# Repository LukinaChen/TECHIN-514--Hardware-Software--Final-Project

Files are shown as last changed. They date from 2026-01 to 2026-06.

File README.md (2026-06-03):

# SnoreSense – A Snoring-Based Sleep Quality Indicator

## Project Overview
SnoreSense is a connected sleep quality indicator designed to help users become aware of their sleep patterns through snoring detection. A sensing device placed near the bed detects and counts snoring events overnight using audio sensing and simple signal processing. The processed data is converted into a sleep quality score and transmitted wirelessly to a paired display device, which visualizes the score using a physical gauge interface.
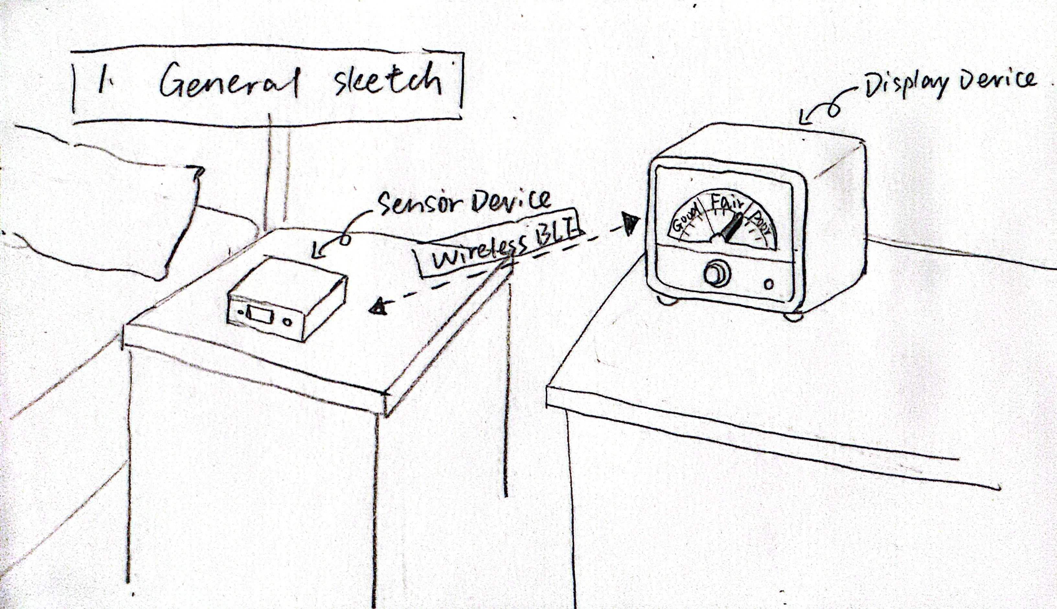
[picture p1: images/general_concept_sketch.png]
General Concept Sketch


## Demo Video
Demo Video (https://www.youtube.com/watch?v=h0CMzlRr8LE)

## Sensor Device – Snoring Detection Unit
The sensing device is placed near the user’s bed and is responsible for detecting snoring activity during sleep. It uses a digital MEMS microphone (INMP441) to capture audio signals and an ESP32 microcontroller to process the data locally. Simple digital signal processing techniques are applied to detect and count snoring events overnight. The summarized results are then transmitted wirelessly to the display device.

**Key hardware components:**

Microcontroller: Seeed Studio XIAO ESP32-C3

Microphone: INMP441 (Part No. 441NP0552) Digital MEMS Microphone

Power: 3.7V 1000mAh LiPo battery

Charging Module: TP4056 Lithium Battery Charger Module

Power Management: SPST Slide Switch for physical battery isolation

Logic: Timed Wake-up strategy (1Hz duty cycle) – The system samples audio for 200ms every second and remains in Deep Sleep for the remaining 800ms.

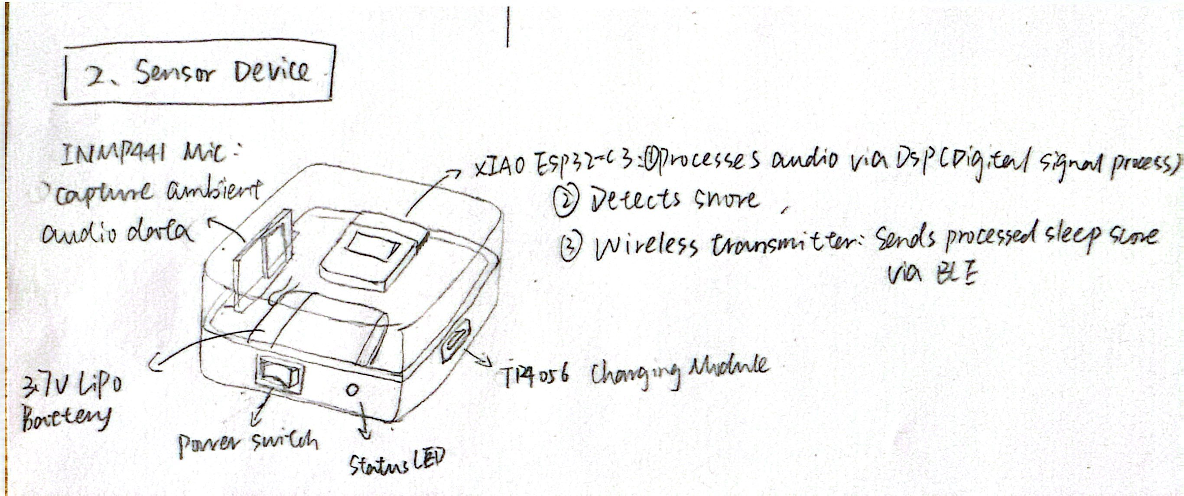
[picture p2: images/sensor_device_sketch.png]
Sensor Device Sketch


The device is designed for fully automated operation. The LED serves as a transient event indicator (5% duty cycle), blinking only when a potential snore is detected or during brief wireless data syncs via ESP-NOW.

**The Scoring Metric** 

1. Total Snore Count: Every 1-second interval that hits the threshold.

2. Bout Count: How many times the user started snoring after at least 2 minutes of silence.

*Logic Criteria (Example for 8hrs)* 
- Good: Minimalsnoring,< 50 total snores AND < 3 Bouts
- Fair: Occasional,snoring,50–200 total snores OR 3–10 Bouts
- Poor: Frequent/Heavy snoring,> 200 total snores OR > 10 Bouts

## Display Device – Sleep Quality Gauge
The display device provides a physical and glanceable visualization of sleep quality data received from the sensing device. It uses a stepper-motor-driven gauge needle to represent sleep quality levels, allowing users to quickly understand their sleep performance.It provides a physical and glanceable visualization of sleep quality data. It features a custom-designed PCB that integrates a high-precision automotive-grade stepper motor and user interaction components.An LED provides a simple on/off indication of snoring activity. The device receives data wirelessly and updates the display accordingly.  

**Key hardware components:**

Microcontroller: Seeed Studio XIAO ESP32-C3 (U1) 

Stepper Motor: Juken X27.168 Stepper Motor (Direct Drive via GPIO)

Indication: Standard 5mm LED (D1) + 220Ω Resistor (R1)

User Input: 6x6mm Tactile push button (SW1) with 10kΩ pull-up resistor (R2) 

Power Solution: 3.7V LiPo battery via JST-PH 2-pin connector (J2)

Power Management: SPST Slide Switch (Master Power) to ensure zero parasitic drain when not in use. 

Circuit Stability: 0.1µF (C1) and 10µF (C2) ceramic capacitors for decoupling and voltage stability. 

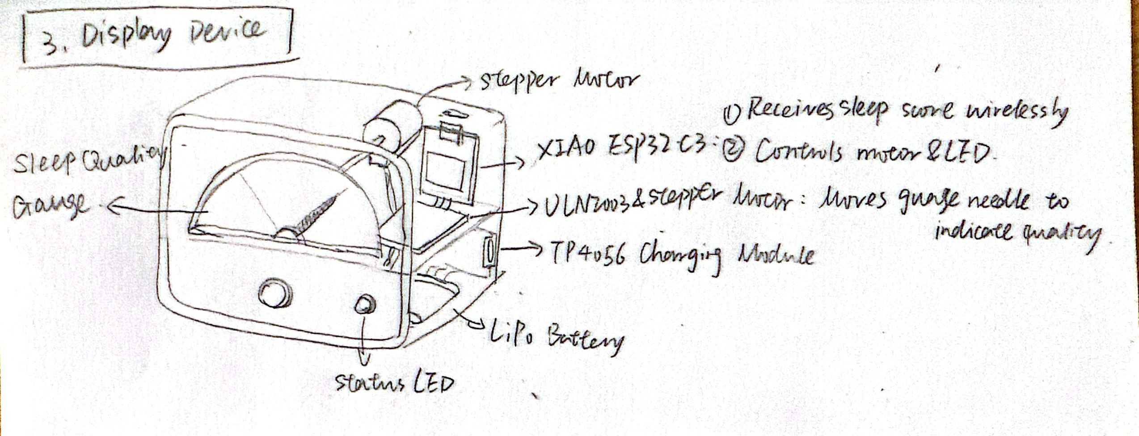
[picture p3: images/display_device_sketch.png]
Display Device Sketch


The X27 stepper motor is only energized when the sleep quality score changes. The Push Button (SW1) allows the user to manually trigger a gauge calibration (homing) or wake the device from deep sleep.

## System Architecture & Communication Diagram
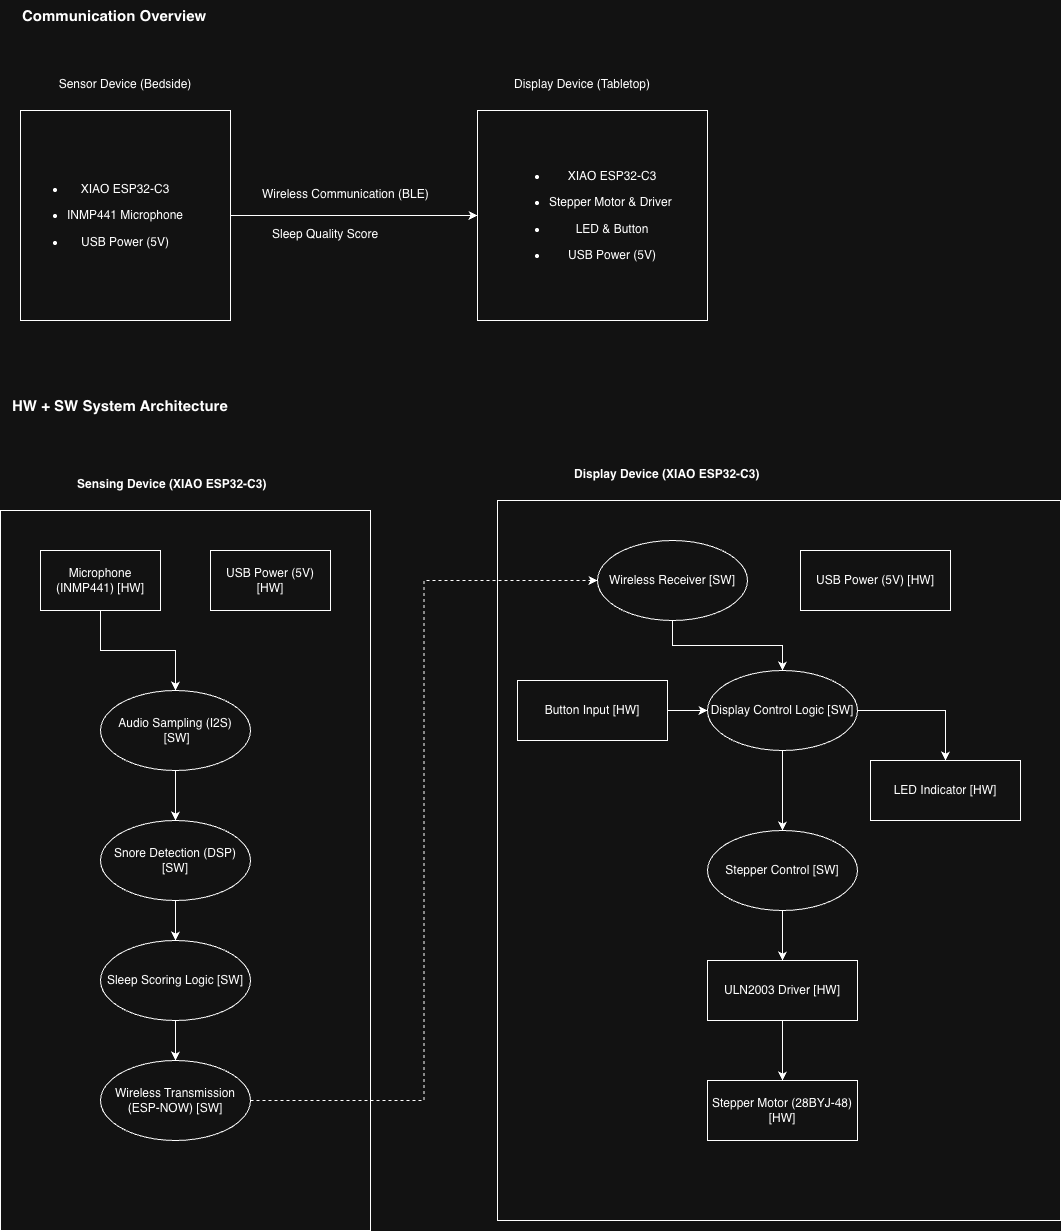
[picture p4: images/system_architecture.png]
System Architecture Diagram


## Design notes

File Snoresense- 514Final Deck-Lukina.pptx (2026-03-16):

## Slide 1

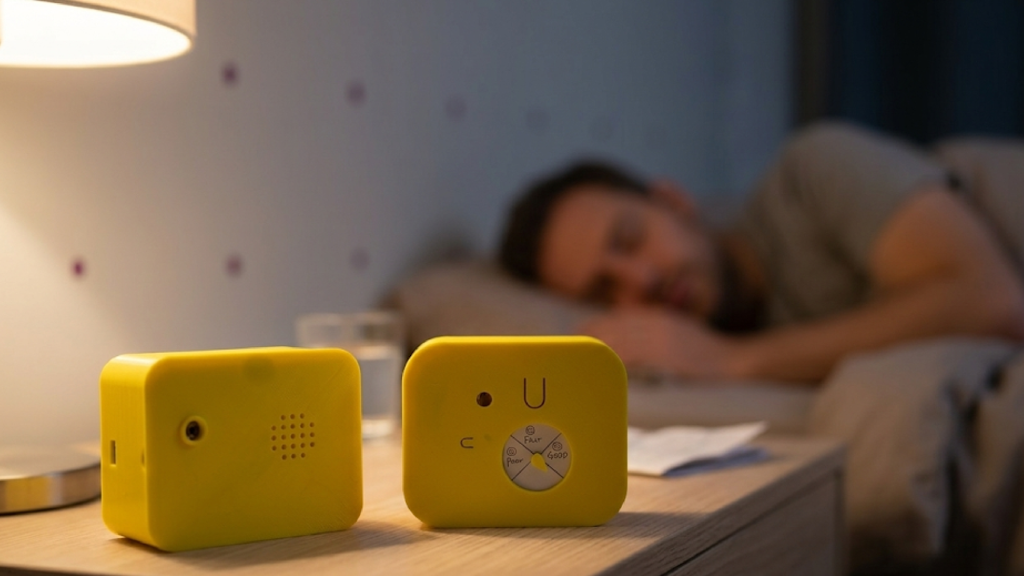
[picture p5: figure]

SnoreSense

A Snoring-Based Sleep Quality Indicator

IOT SLEEP MONITORING SYSTEM

GitHub repo: https://github.com/LukinaChen/TECHIN-514--Hardware-Software--Final-Project

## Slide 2

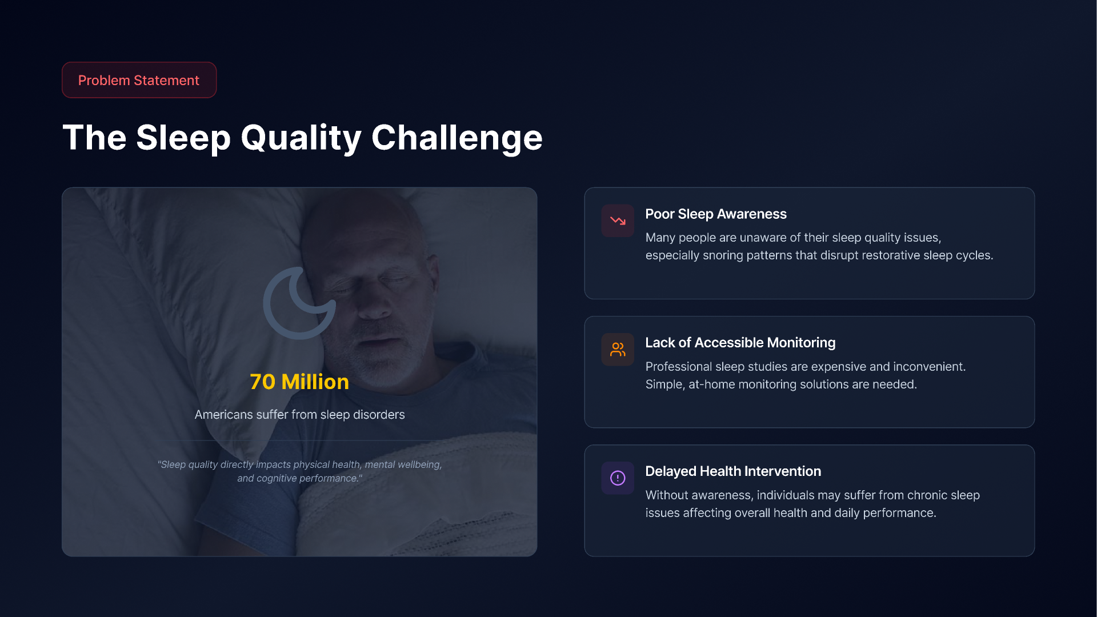
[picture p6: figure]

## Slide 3

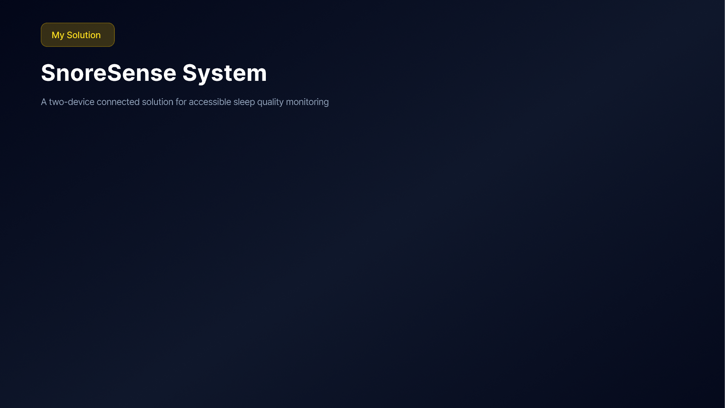
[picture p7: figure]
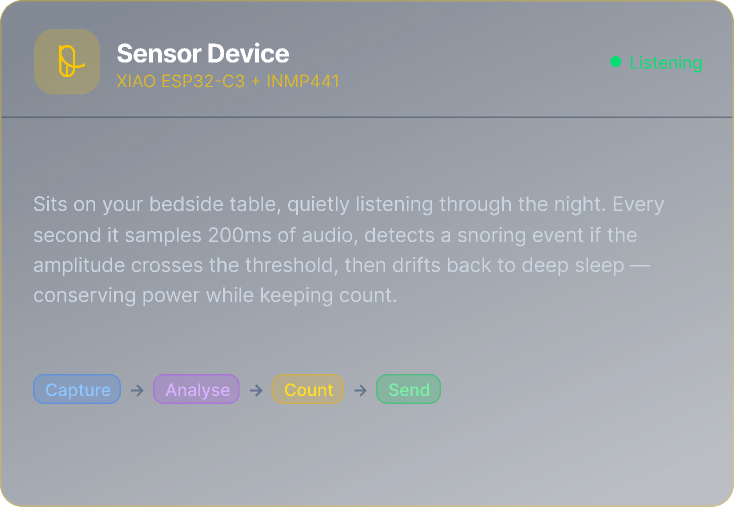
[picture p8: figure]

ESP-NOW

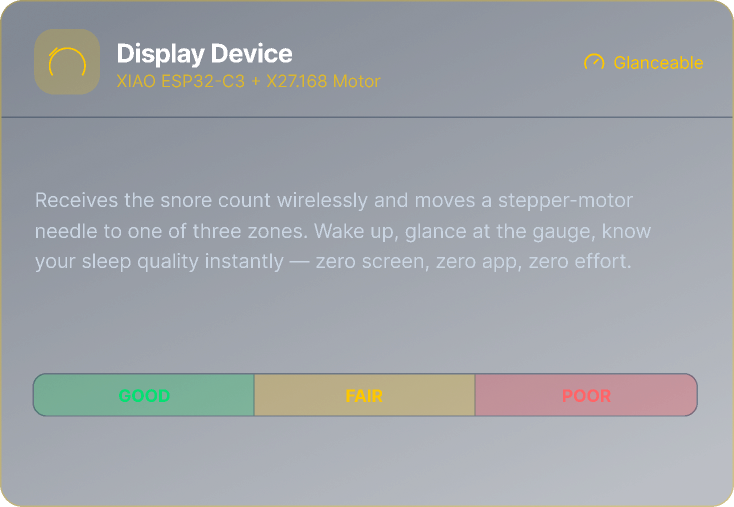
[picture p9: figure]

Wireless ESP-NOW

Direct peer-to-peer, no router needed

Ultra-Low Power

Multi-night runtime on a single charge

No App Required

Physical gauge — readable in seconds

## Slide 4

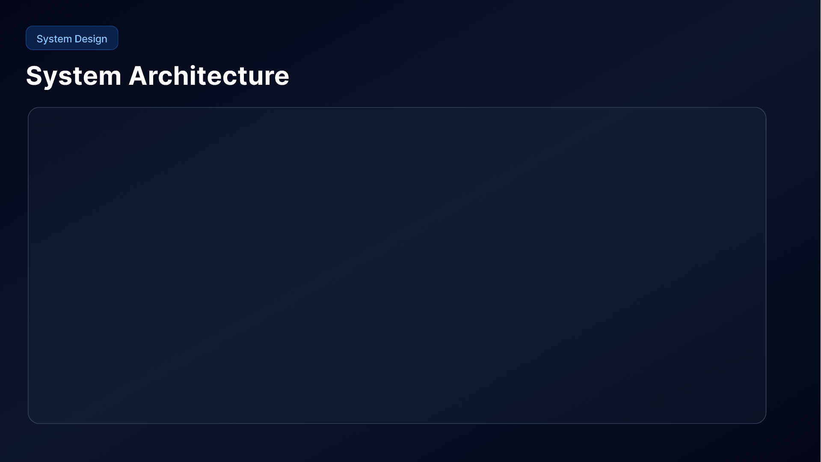
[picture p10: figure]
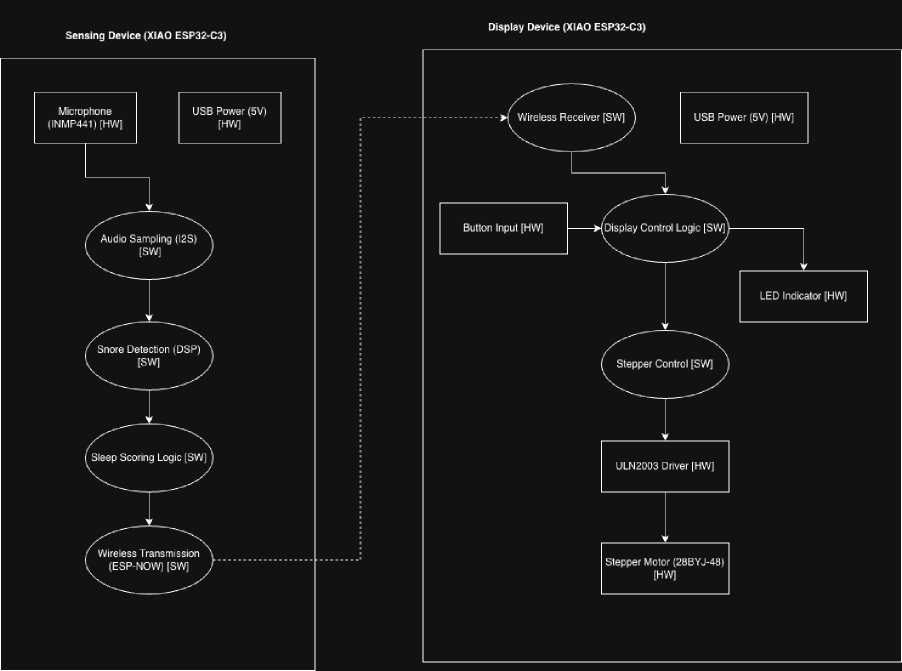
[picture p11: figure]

4 / 12

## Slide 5

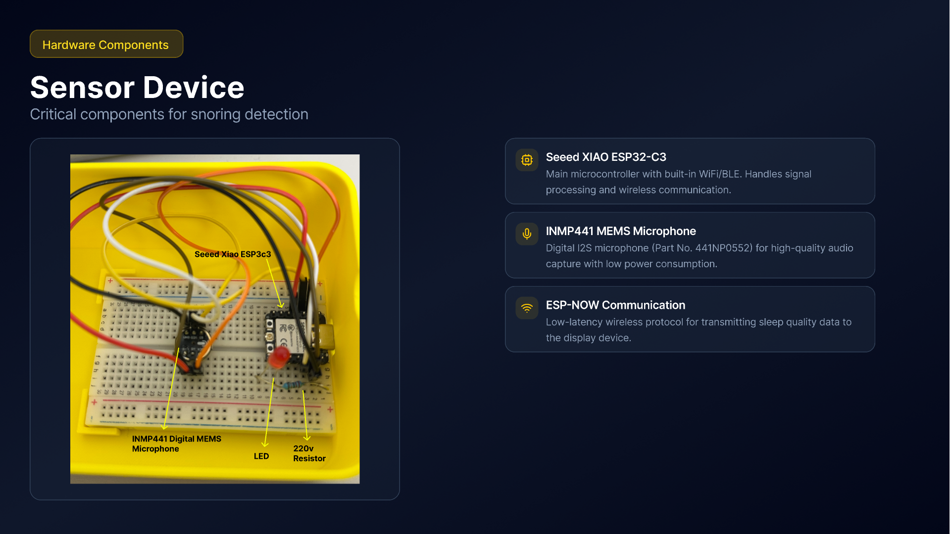
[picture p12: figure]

5 / 12

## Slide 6

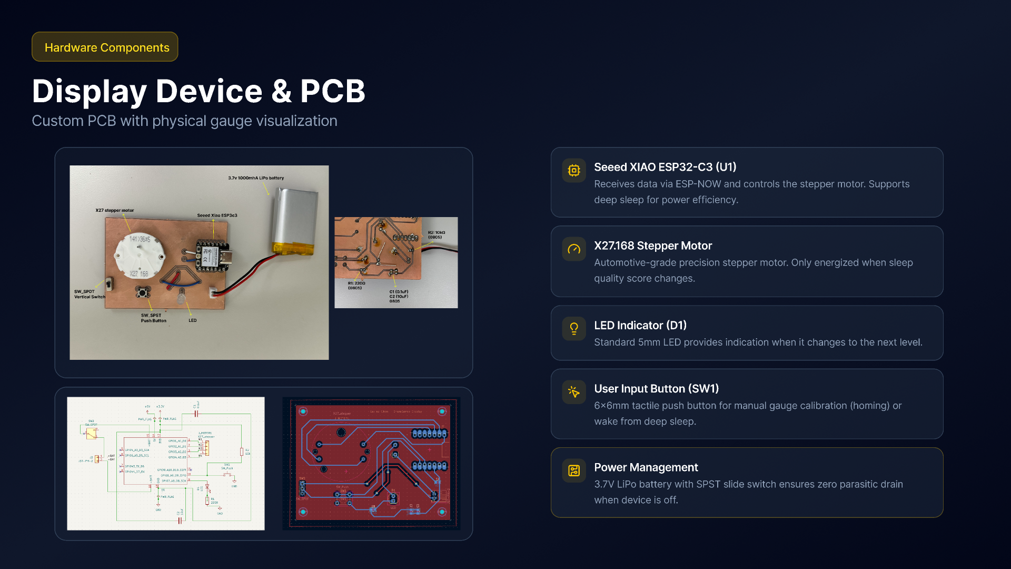
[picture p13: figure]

6 / 12

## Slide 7

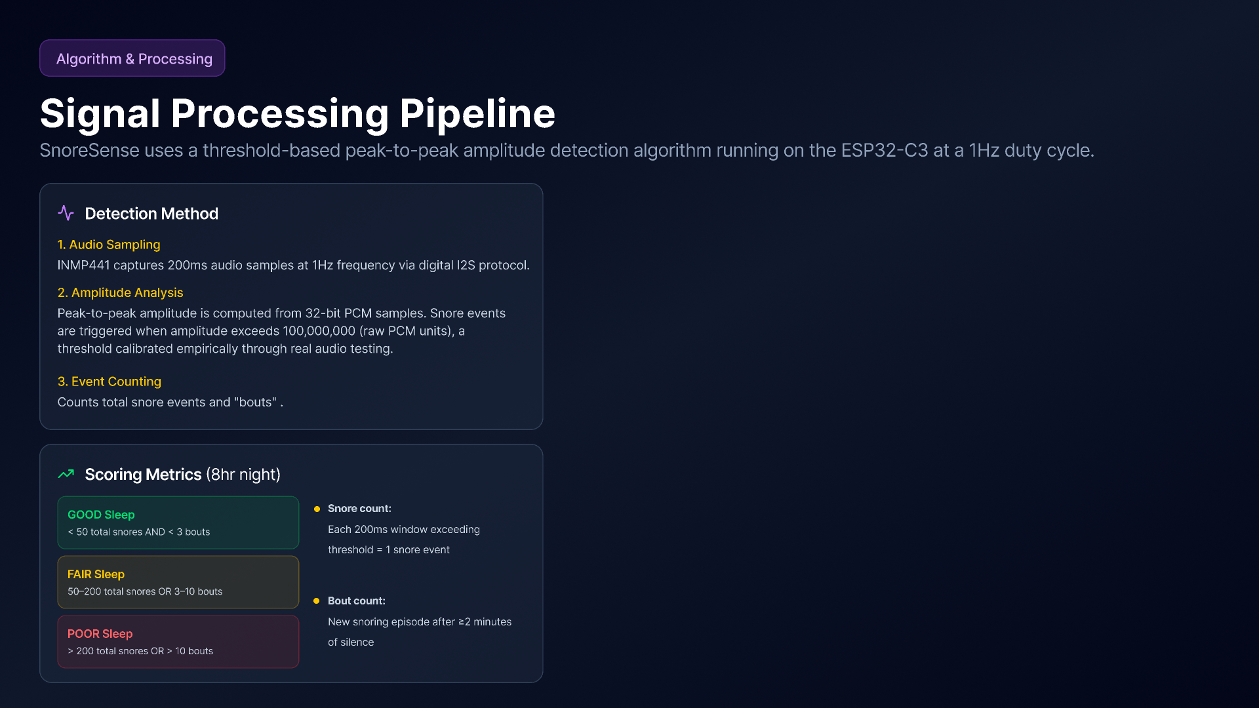
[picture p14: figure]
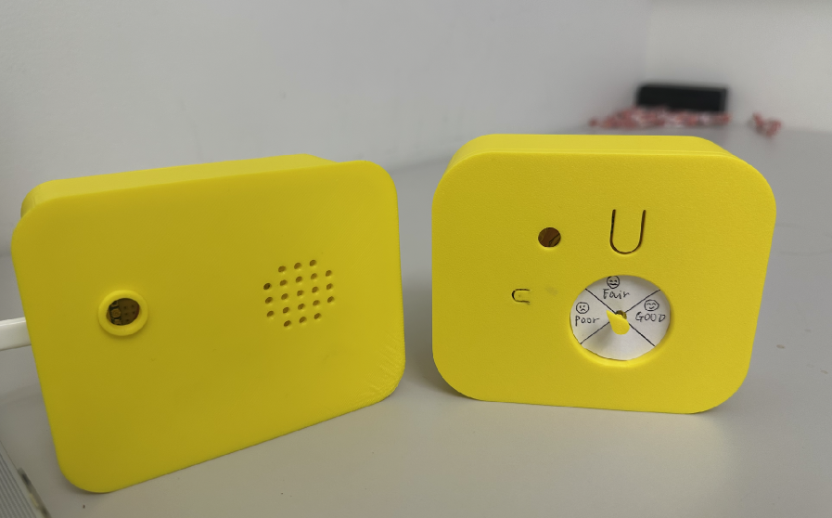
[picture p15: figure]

7 / 12

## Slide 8

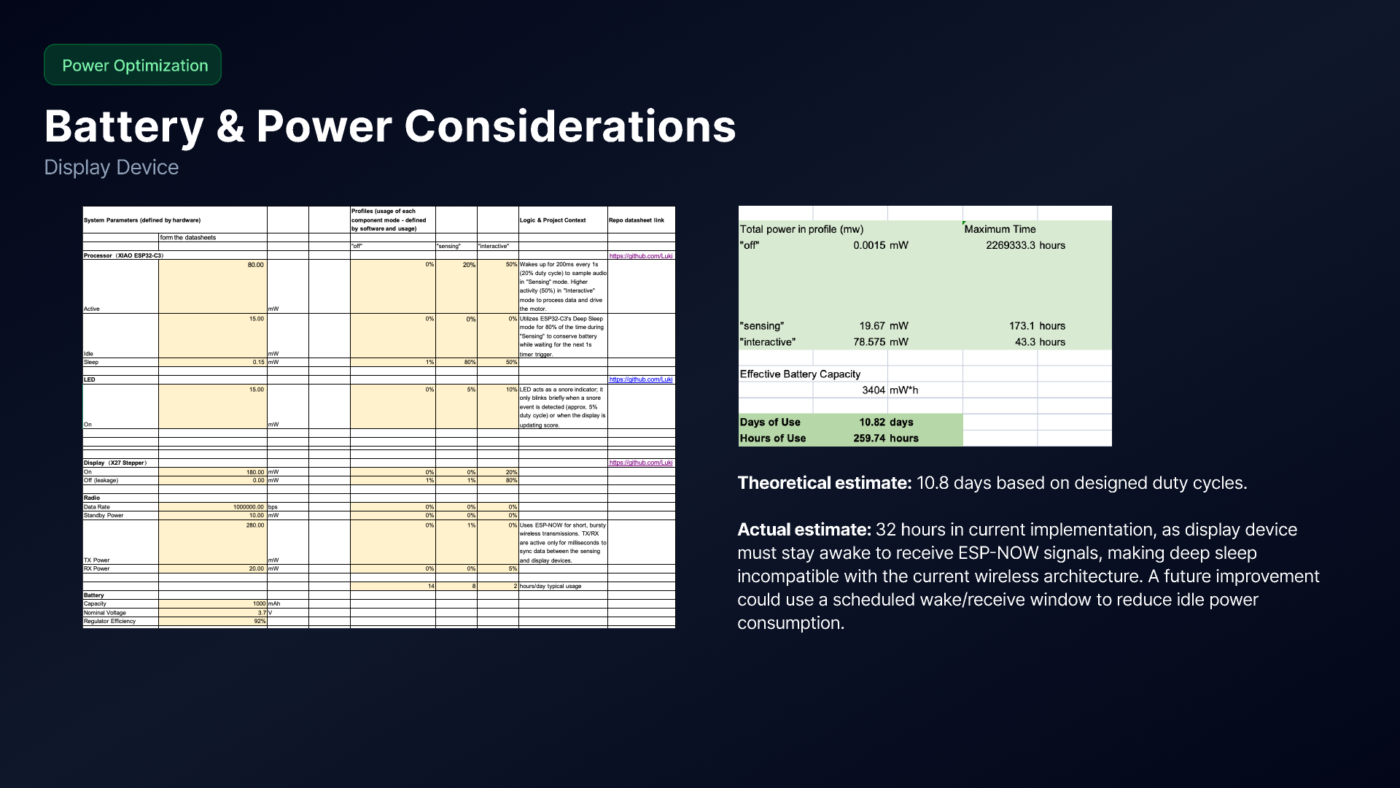
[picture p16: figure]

8 / 12

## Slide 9

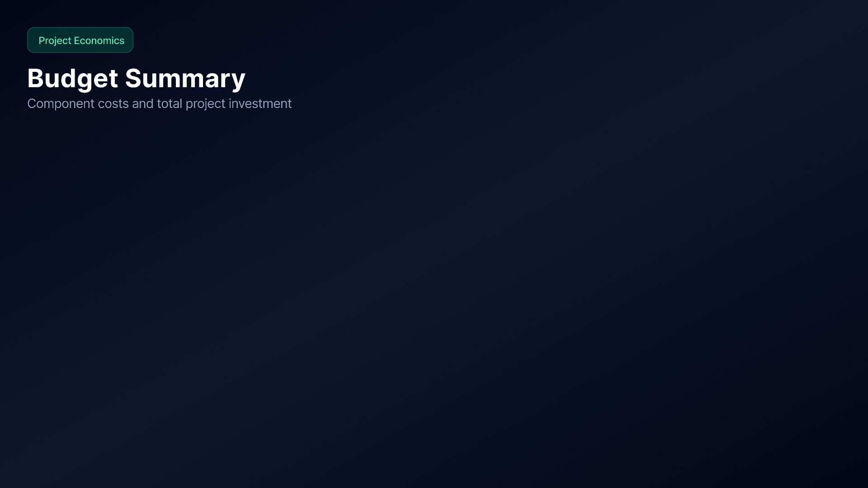
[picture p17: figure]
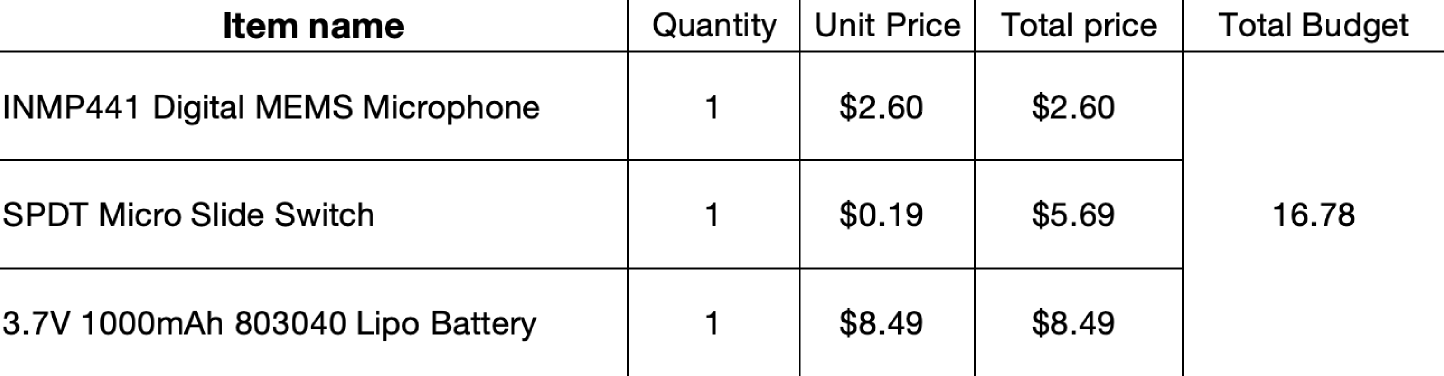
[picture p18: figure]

9 / 12

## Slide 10

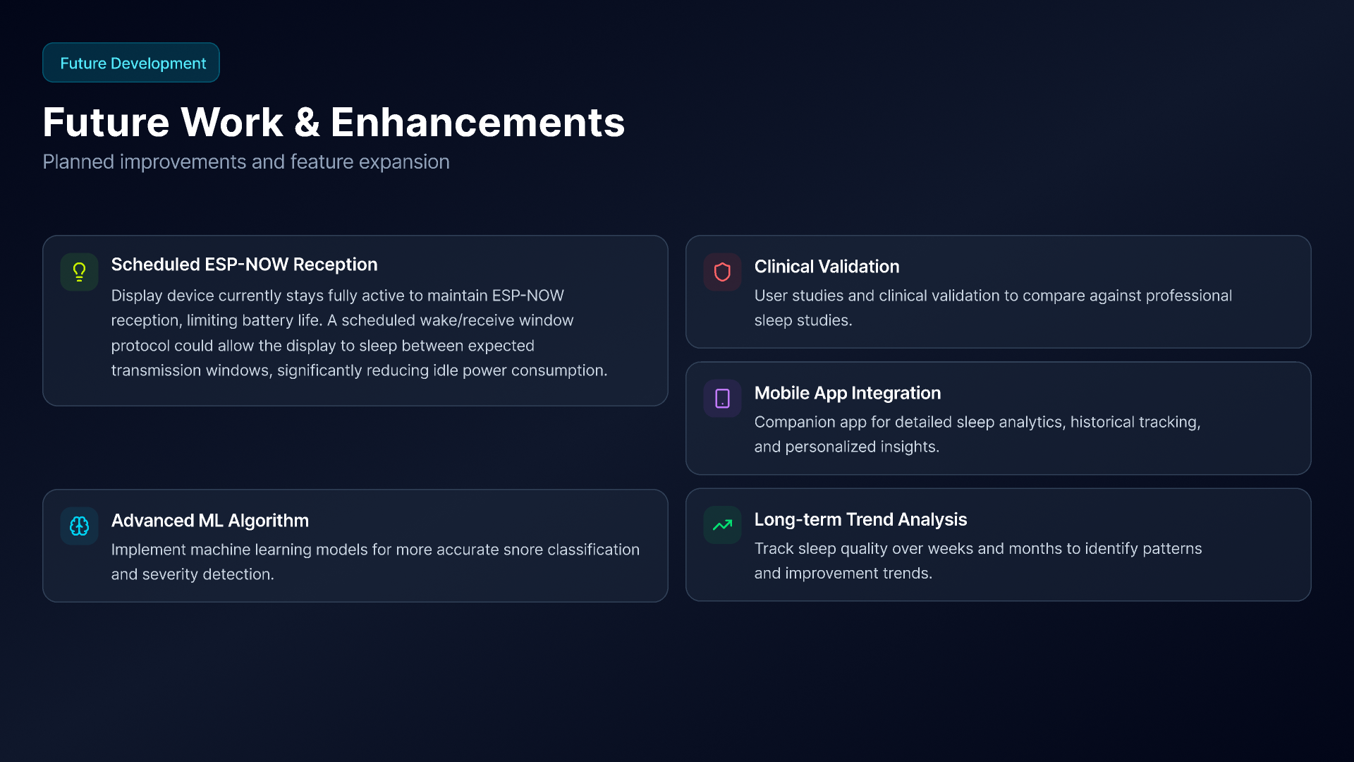
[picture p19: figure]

11 / 12

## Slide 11

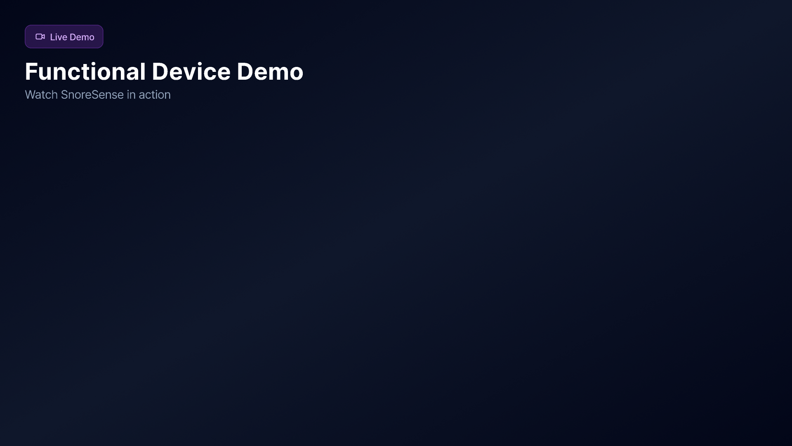
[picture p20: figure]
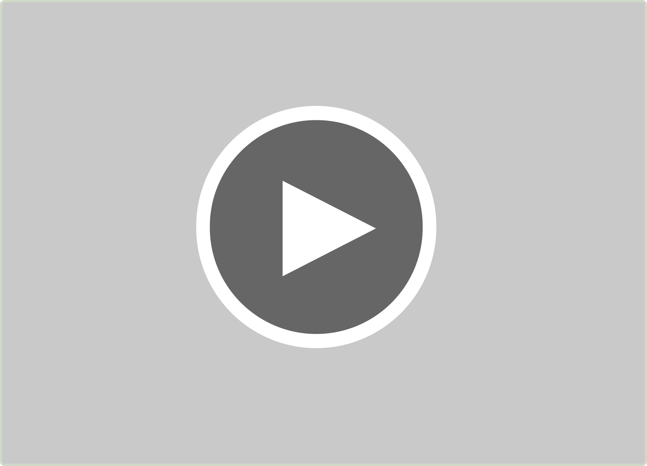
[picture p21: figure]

12 / 12

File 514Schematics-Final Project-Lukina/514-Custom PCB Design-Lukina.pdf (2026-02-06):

### 514-Custom PCB Design

1) All the electronic components that will be soldered to display PCB

Main Control & Interface:

- Microcontroller: Seeed Studio XIAO ESP32-C3 (U1) – Soldered via header pins
- Stepper Motor: X27.168 Stepper Motor (4-pin) – Soldered via through-holes
- Battery Connector: JST-PH 2-pin Connector (2.0mm pitch, right-angle) (J2)
- User Button: 6×6mm Tactile Switch (SW1)

Resistors & LED:

- Resistor (R1): 220Ω – LED current limiting
- Resistor (R2): 10kΩ – Button pull-up resistor
- LED: 5mm LED (Through-hole) (D1)

Capacitors:

- Capacitor (C1): 0.1µF Ceramic – Decoupling
- Capacitor (C2): 10µF Ceramic – Bulk capacitance for 3.3V rail
2) A screenshot of circuit in the Schematic Editor window of KiCad

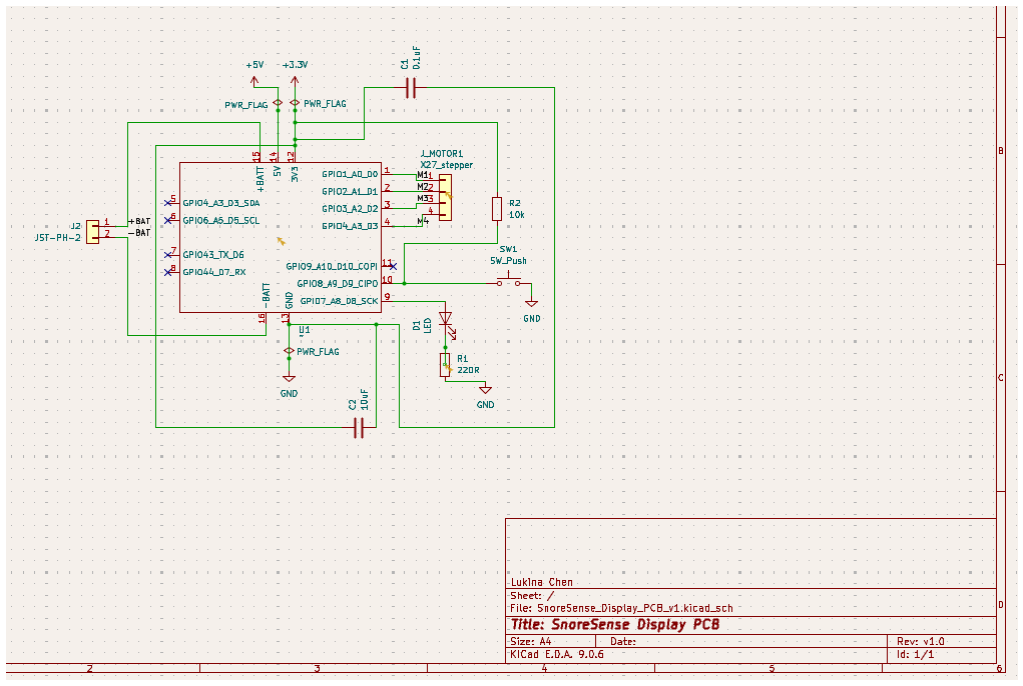
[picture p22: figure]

3) A screenshot of circuit board in the PCB Editor window of KiCad

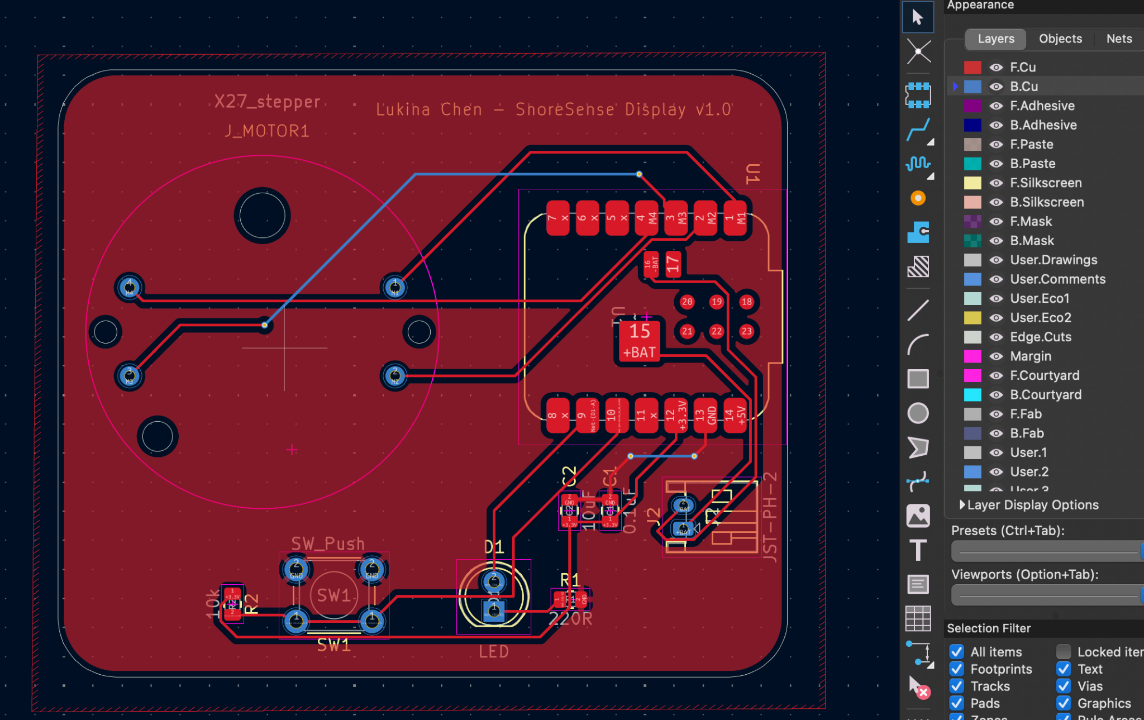
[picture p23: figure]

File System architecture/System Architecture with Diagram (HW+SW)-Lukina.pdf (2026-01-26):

README.md | 2026-01-19

# SnoreSense – A Snoring-Based Sleep Quality Indicator

## Project Overview

SnoreSense is a connected sleep quality indicator designed to help users become aware of their sleep patterns through snoring detection. A sensing device placed near the bed detects and counts snoring events overnight using audio sensing and simple signal processing. The processed data is converted into a sleep quality score and transmitted wirelessly to a paired display device, which visualizes the score using a physical gauge interface.


## Sensor Device – Snoring Detection Unit

The sensing device is placed near the userʼs bed and is responsible for detecting snoring activity during sleep. It uses a digital MEMS microphone (INMP441) to capture audio signals and an ESP32 microcontroller to process the data locally. Simple digital signal processing techniques are applied to detect and count snoring events overnight. The summarized results are then transmitted wirelessly to the display device.

Key hardware components:

Microcontroller: Seeed Studio XIAO ESP32-C3
Microphone: INMP441 Digital MEMS Microphone Power: 3.7V LiPo battery

Charging Module：TP4056 Lithium Battery Charger Module


The sensing device is designed for overnight operation and employs local processing and low-power wireless communication to reduce energy consumption.

## Display Device – Sleep Quality Gauge

The display device provides a physical and glanceable visualization of sleep quality data received from the sensing device. It uses a stepper-motor-driven gauge needle to represent sleep quality levels, allowing users to quickly understand their sleep performance. An LED provides a simple on/off indication of snoring activity. The device receives data wirelessly and updates the display accordingly.

Key hardware components:

Microcontroller: Seeed Studio XIAO ESP32-C3
Stepper Motor: 28BYJ-48 Stepper Motor with ULN2003 Driver Motor Driver: ULN2003 Driver Board
Indication: Standard 5mm LED + 220Ω Resistor
Input: 6x6x5mm Tactile push button
Power: 3.7V LiPo battery


The stepper motor is only activated when the displayed value changes, minimizing power consumption.

## System Architecture & Communication Diagram

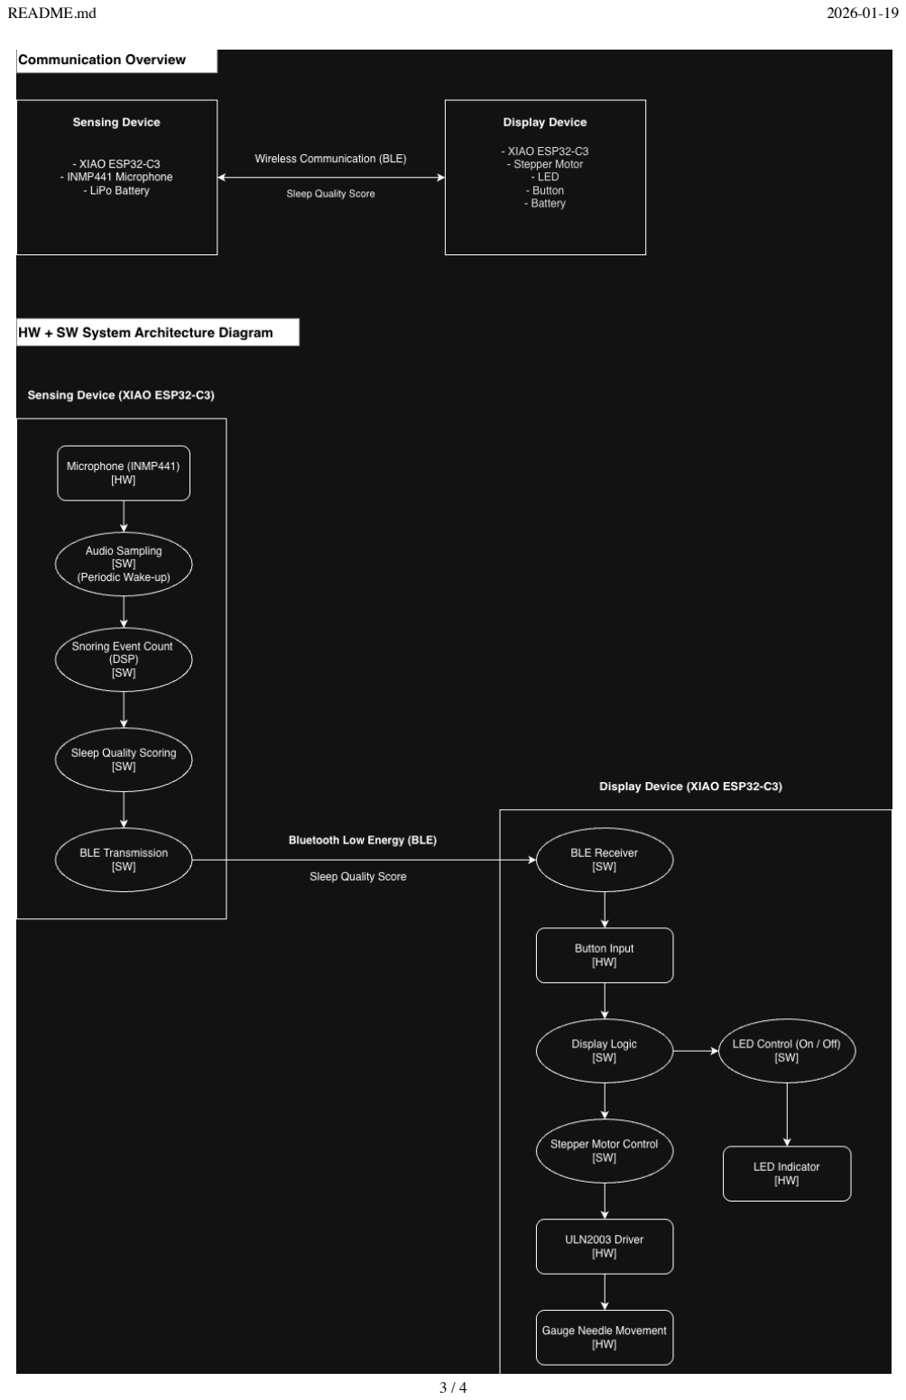
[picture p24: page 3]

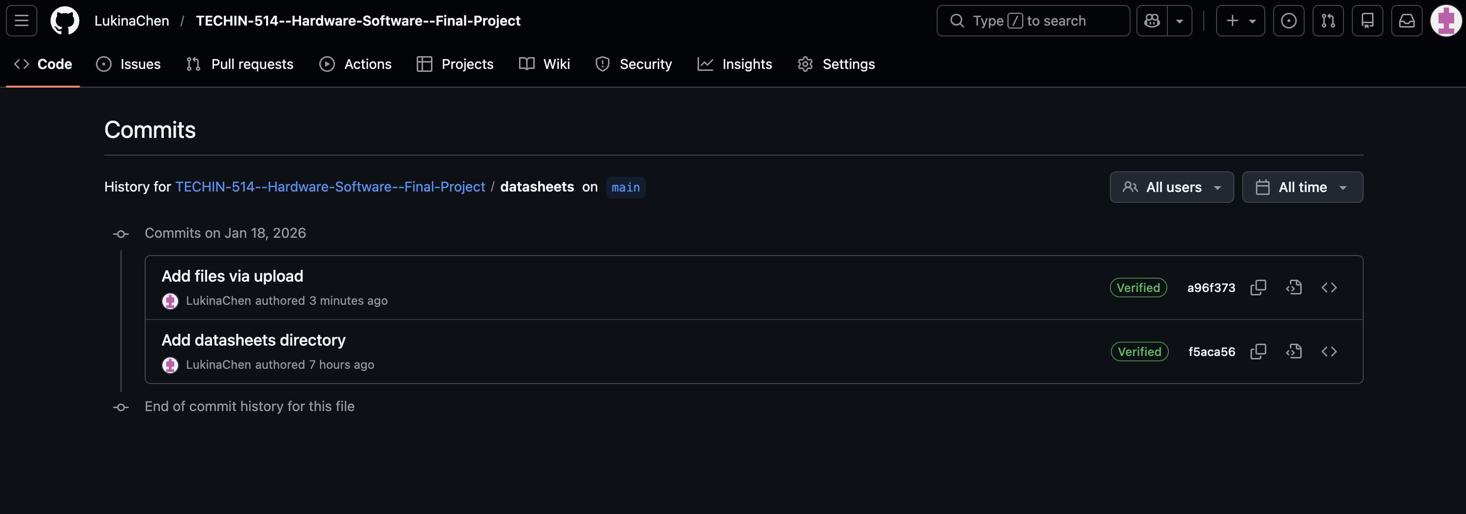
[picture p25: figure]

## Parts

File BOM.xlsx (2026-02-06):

Item ID | Component Name | Description | Part Number | Quantity | Supplier / Notes
1 | Microcontroller | MCU with WiFi/BLE, RISC-V core | Seeed Studio XIAO ESP32-C3 | 2 | 1 for Sensor Device, 1 for Display Device
2 | Microphone | Omnidirectional I2S Digital MEMS Microphone | INMP441 | 1 | For Sensor Device (High precision, Low noise)
3 | Stepper Motor | x27 stepper motor | 28BYJ-48 (5V Version) (TBD) | 1 | For Display Device Gauge
4 | Motor Driver | Darlington Transistor Array Driver Board | ULN2003 Module (TBD) | 1 | Usually sold as a kit with 28BYJ-48
5 | LED | 5mm Red LED (Through-hole) | Generic | 1 | For Snore Activity Indicator
6 | Resistor | 220Ω or 330Ω, 1/4W, 5% | Generic | 1 | Current limiting for LED (Essential)
7 | Push Button | 6x6x5mm Tactile Switch | Generic (B3F series compatible) | 1 | For Reset / User Interaction
8 | USB Cable | USB Type-C Cable | Generic | 2 | Power supply & Data upload for both units
9 | Prototyping Board | PCB | Generic | 2 | For circuit assembly
10 | Jumper Wires | M-M, M-F, F-F DuPont Wires | Generic | 1 Pack | For connections

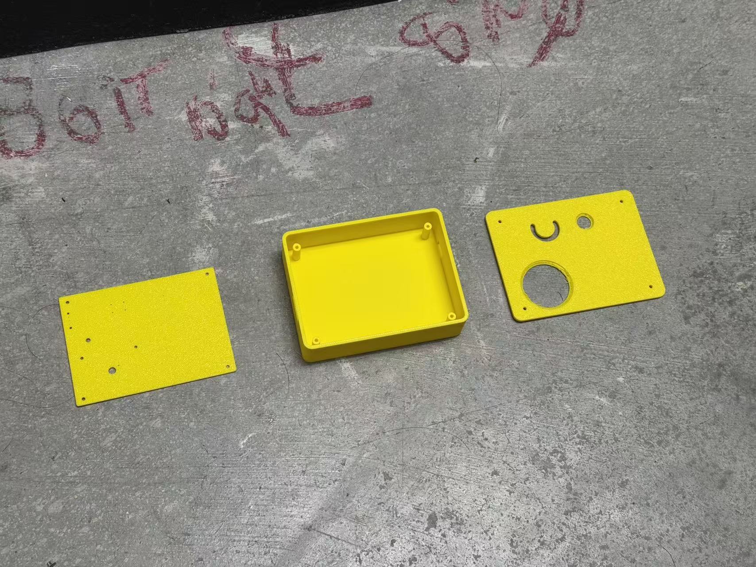
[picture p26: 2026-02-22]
Display Enclosure/parts laid out separately.JPG

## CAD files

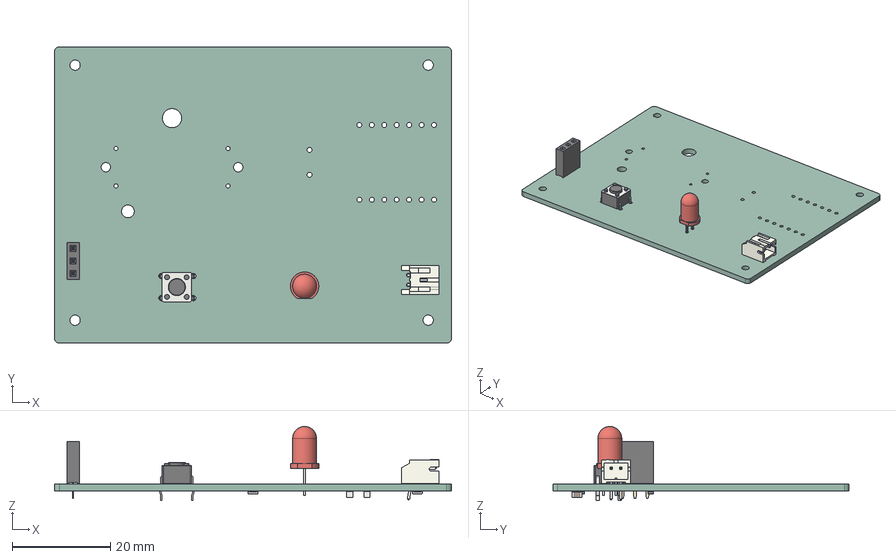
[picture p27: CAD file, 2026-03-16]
Display Enclosure/SnoreSense_Display_PCB_v6.step
81.0 x 60.5 x 15.1 mm
JST_PH_S2B-PH-K_1x02_P2.00mm_Horizontal
LED_D5.0mm
PinSocket_1x03_P2.54mm_Vertical
SW_PUSH_6mm
C_0805_2012Metric x 2
R_0805_2012Metric x 2
SnoreSense_Display_PCB_v1_PCB

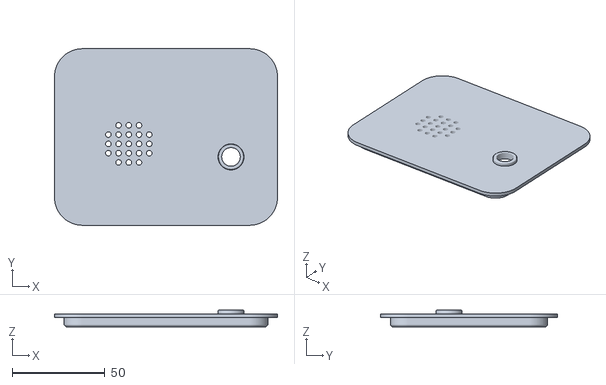
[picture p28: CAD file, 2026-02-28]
Sensor Enclosure/Top case- Lukina.stl
120.0 x 95.0 x 9.00

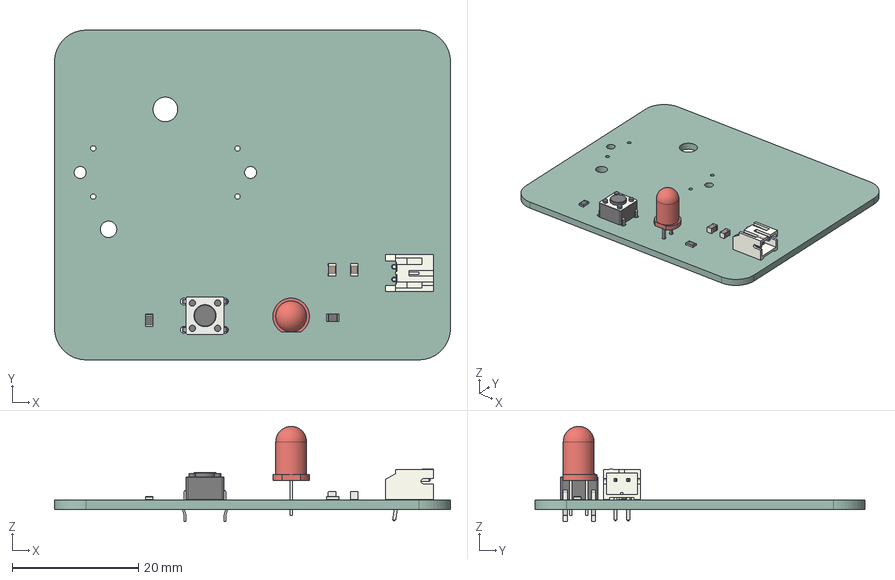
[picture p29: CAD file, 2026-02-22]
SnoreSense_Display_PCB_v1/SnoreSense_Display_PCB_v1.step
62.8 x 52.2 x 15.1 mm
C_0805_2012Metric x 2
R_0805_2012Metric x 2
JST_PH_S2B-PH-K_1x02_P2.00mm_Horizontal
LED_D5.0mm
SW_PUSH_6mm
SnoreSense_Display_PCB_v1_PCB

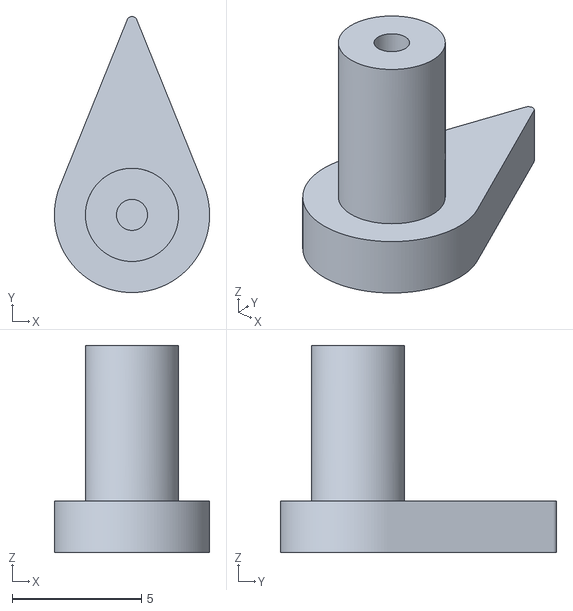
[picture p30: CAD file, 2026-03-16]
Display Enclosure/Needle1-Lukina.stl
6.00 x 10.7 x 8.00

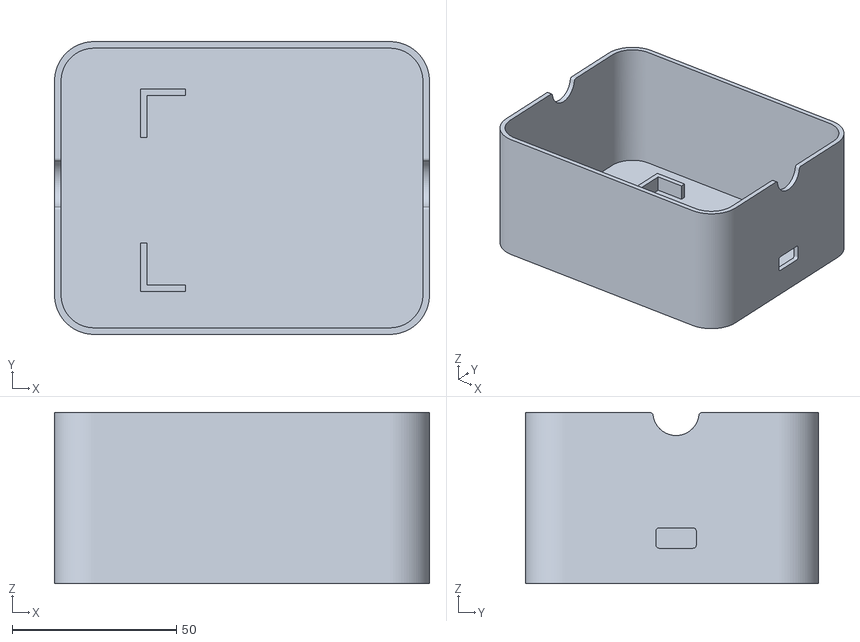
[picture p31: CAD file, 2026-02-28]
Sensor Enclosure/Buttom case- Lukina.stl
114.0 x 89.0 x 52.0

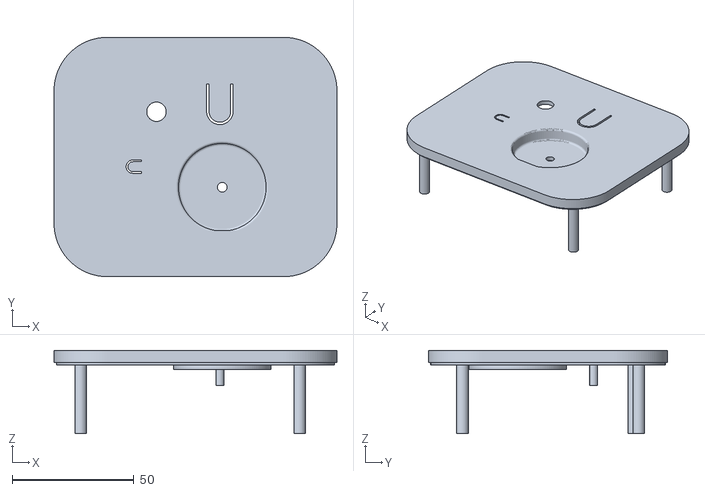
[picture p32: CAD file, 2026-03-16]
Display Enclosure/Topcase1--Lukina.stl
116.3 x 98.4 x 34.3

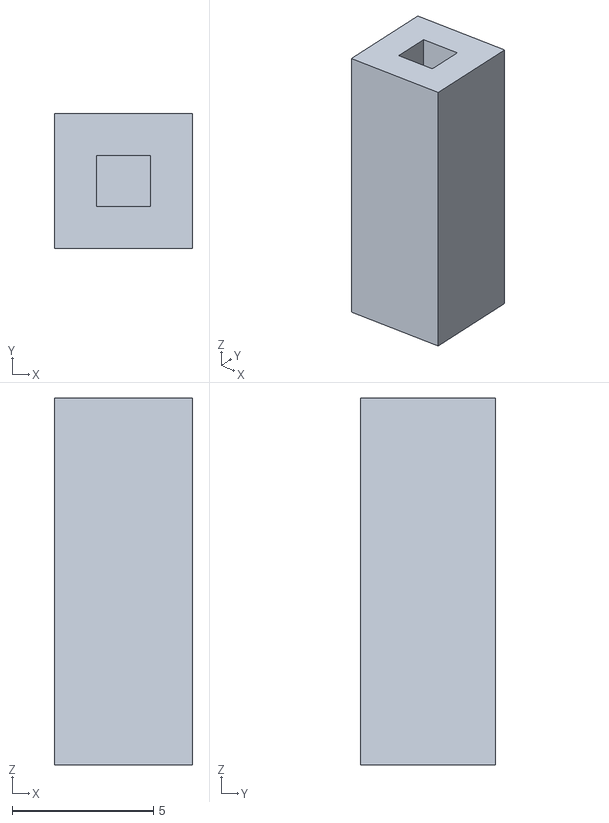
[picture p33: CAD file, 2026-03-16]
Display Enclosure/Slide2Lukina.stl
4.89 x 4.79 x 13.0

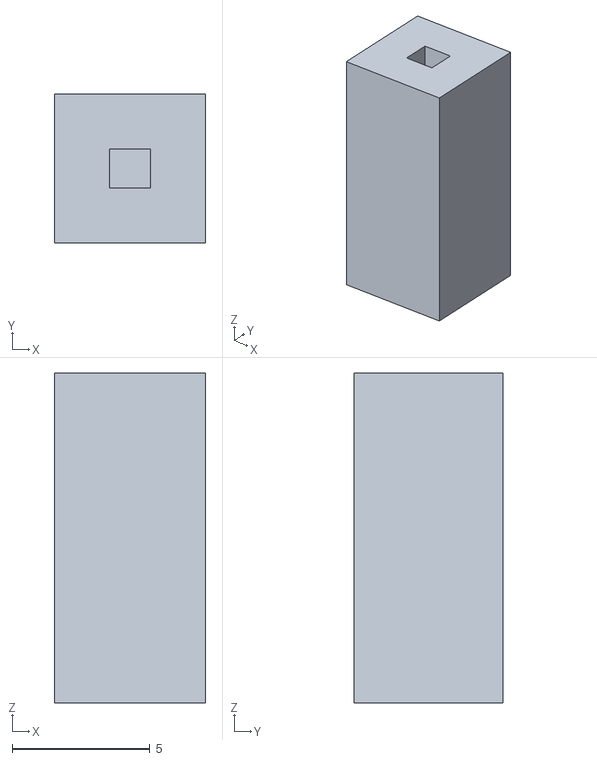
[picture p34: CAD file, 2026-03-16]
Display Enclosure/Slide--Lukina.stl
5.50 x 5.40 x 12.0

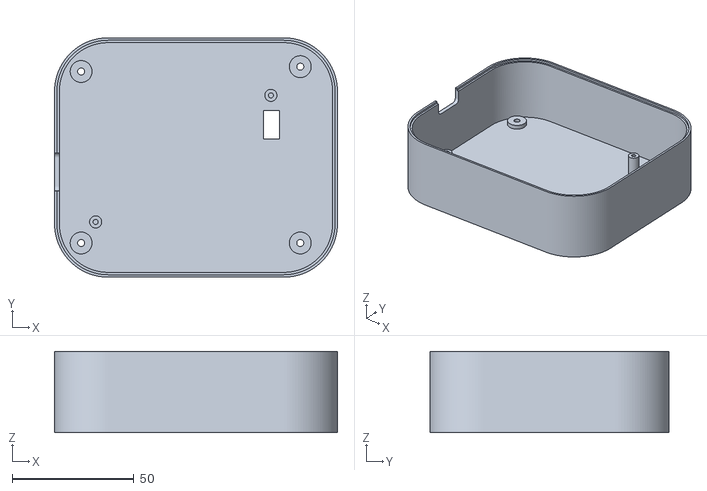
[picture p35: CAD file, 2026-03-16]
Display Enclosure/Bottomcase--Lukina.stl
116.3 x 98.4 x 33.3

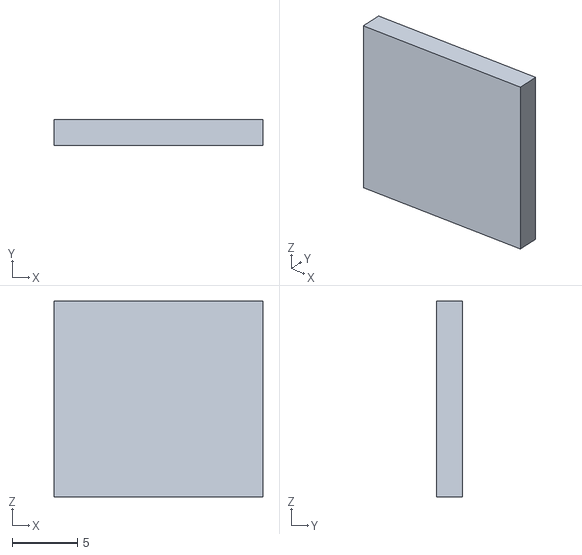
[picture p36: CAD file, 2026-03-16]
Display Enclosure/Rack1-Lukina.stl
16.0 x 2.00 x 15.0

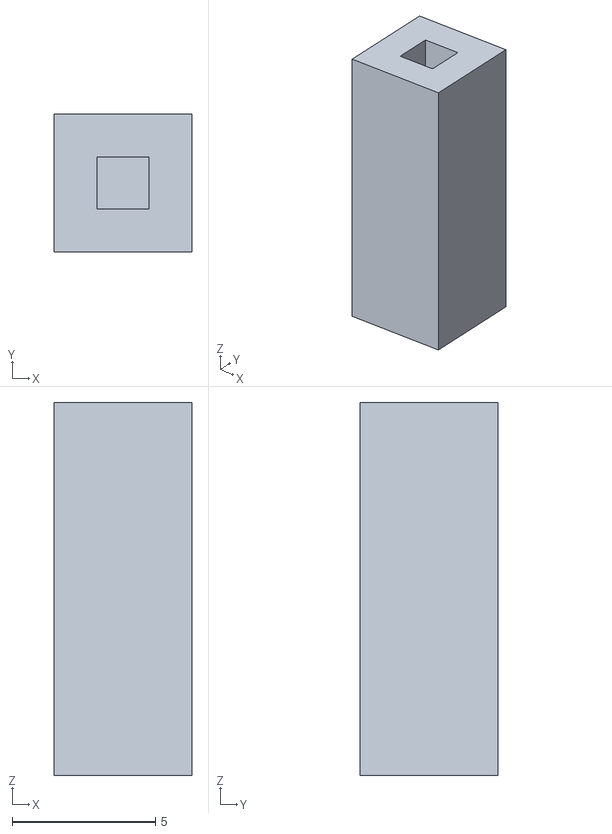
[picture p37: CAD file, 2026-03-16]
Display Enclosure/Slide4-Lukina.stl
4.79 x 4.79 x 13.0

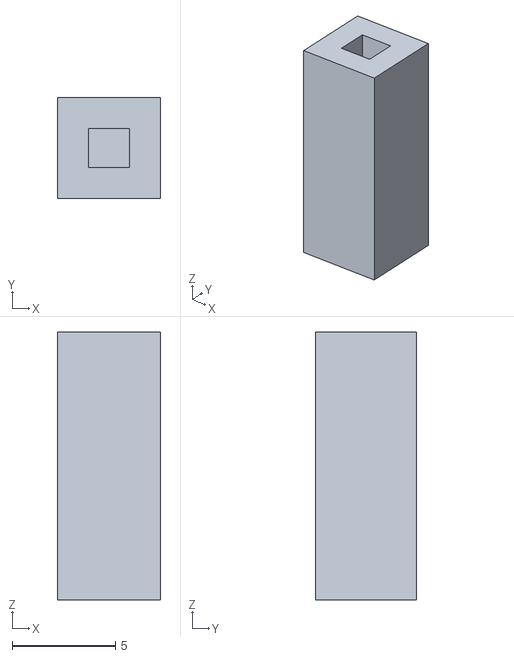
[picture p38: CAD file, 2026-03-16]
Display Enclosure/Slide3-Lukina.stl
4.99 x 4.89 x 13.0

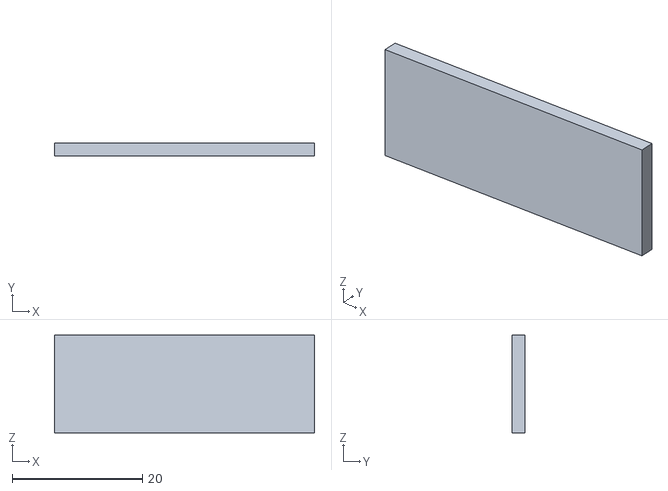
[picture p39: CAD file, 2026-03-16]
Display Enclosure/Rack2-Lukina.stl
40.0 x 2.00 x 15.0

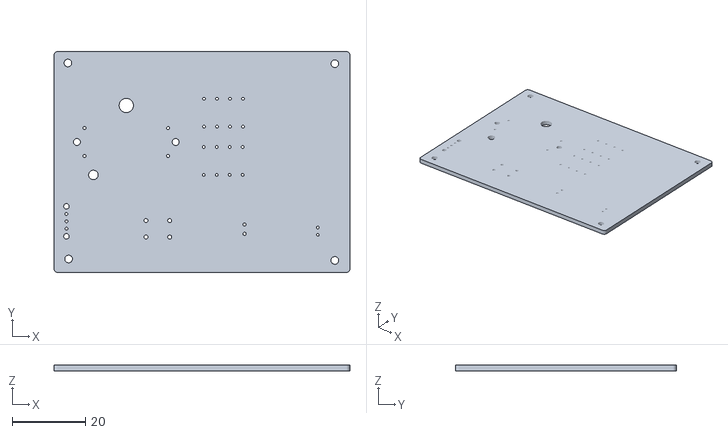
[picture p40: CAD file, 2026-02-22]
Display Enclosure/PCB-Body-Lukina.stl
80.9 x 60.4 x 1.51

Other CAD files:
Display Enclosure/Needle2-Lukina.stl
Display Enclosure/Topcase--Lukina.stl
Display Enclosure/PCB Source_v3.step
Display Enclosure/PCB Source_v3-Lukina.stl
Display Enclosure/Bottom_Case-Lukina.stl
Display Enclosure/Bottomcase-Lukina.stl
Display Enclosure/Display_Enclosure_Native.f3d
Display Enclosure/Enclosure-Display_step.step
Display Enclosure/Slide-Lukina.stl
Display Enclosure/Top case-Lukina.stl

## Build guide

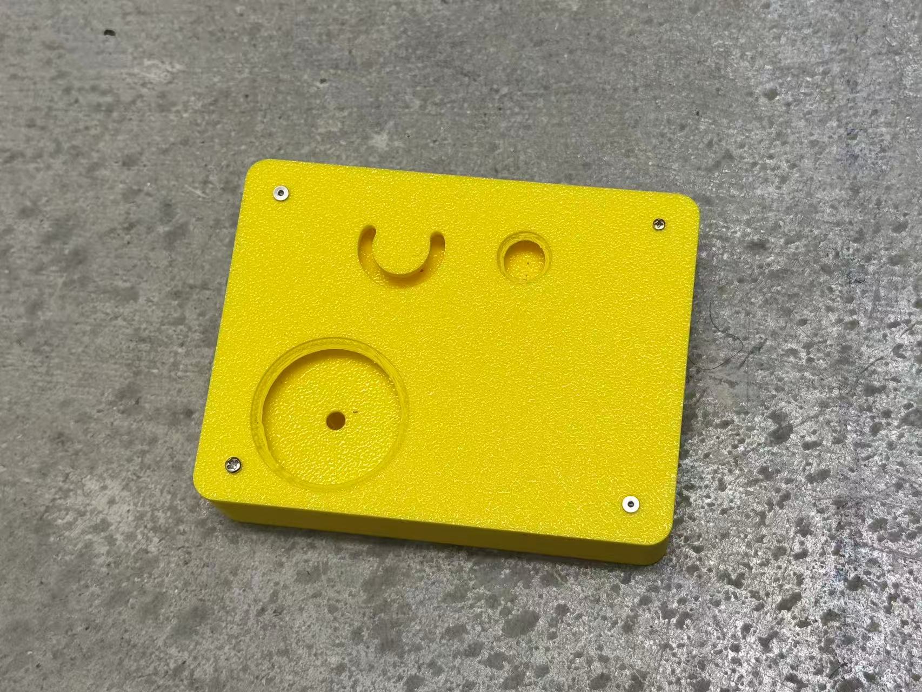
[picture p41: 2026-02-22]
Display Enclosure/assembled2.jpeg

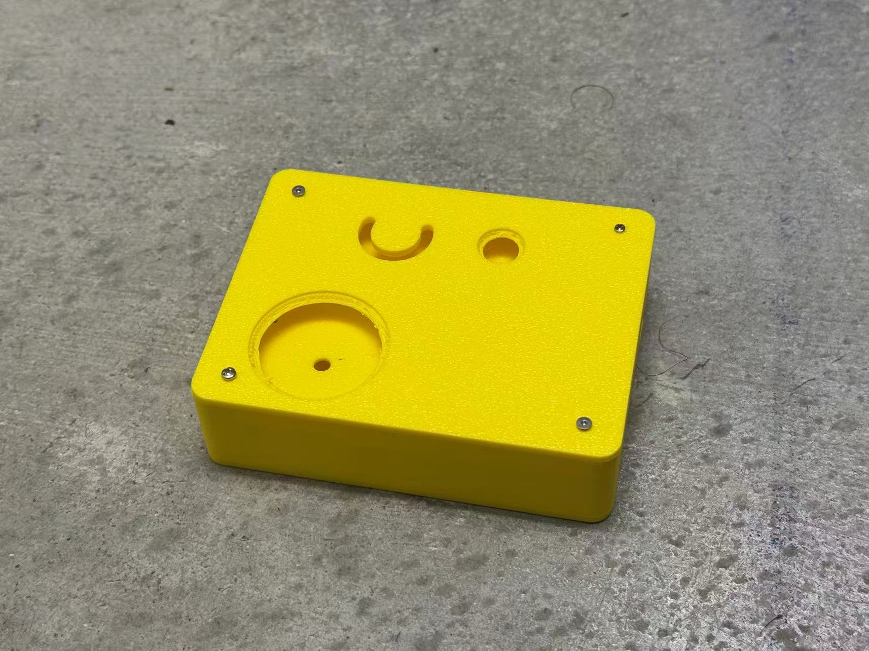
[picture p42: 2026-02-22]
Display Enclosure/Assembled.jpeg

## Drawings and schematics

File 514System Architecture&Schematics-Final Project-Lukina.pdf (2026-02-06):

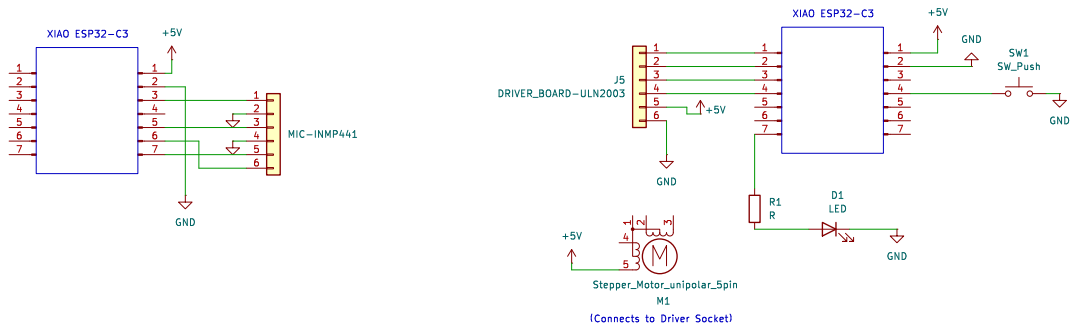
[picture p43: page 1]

Id: 1/1 Title: SnoreSense System Schematic

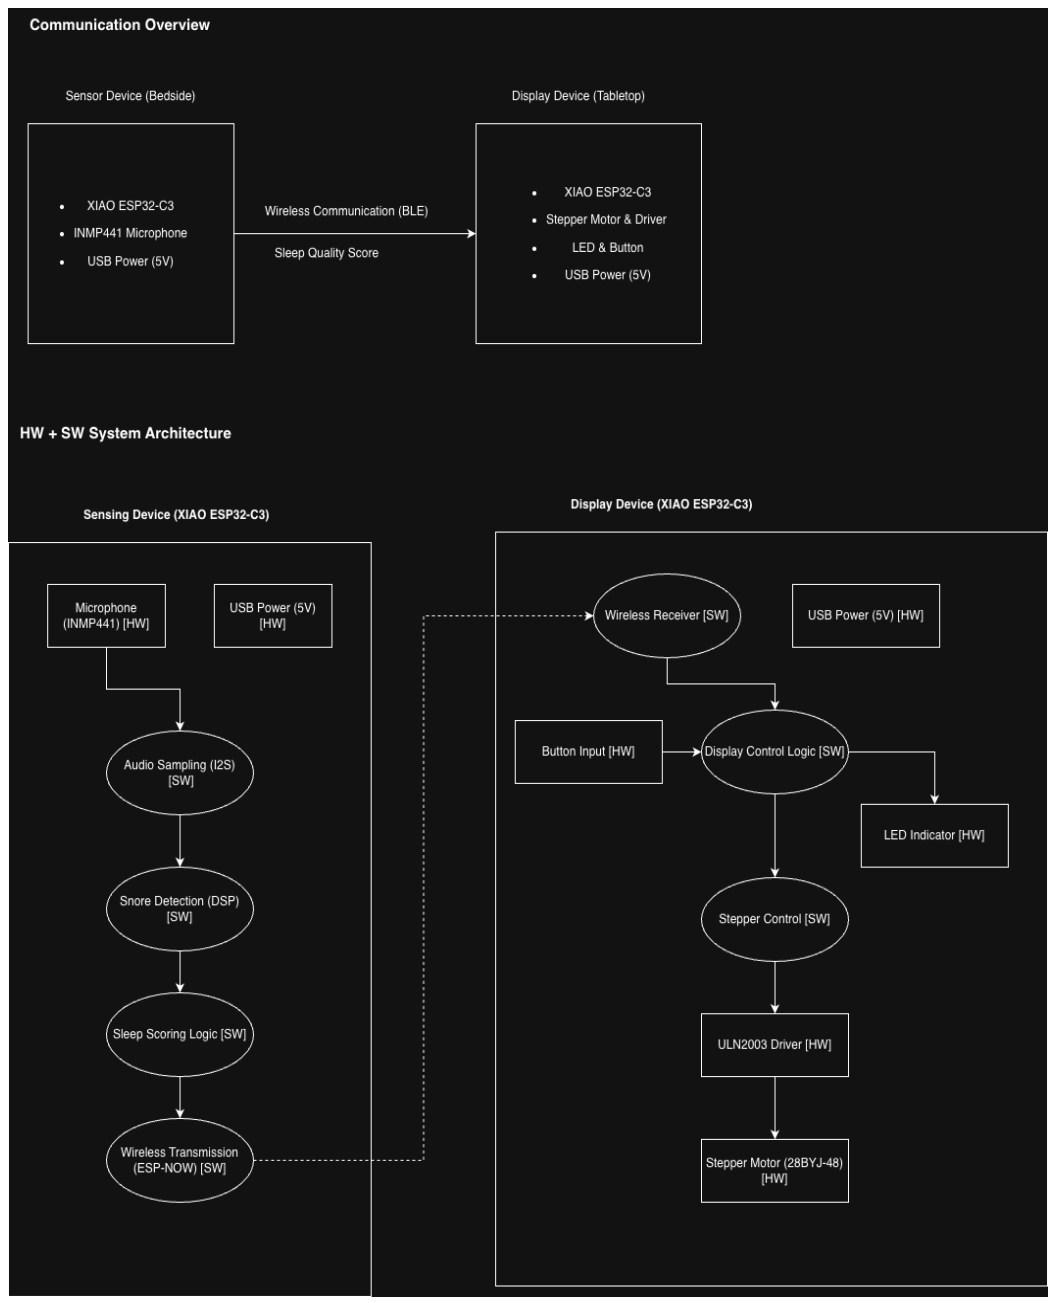
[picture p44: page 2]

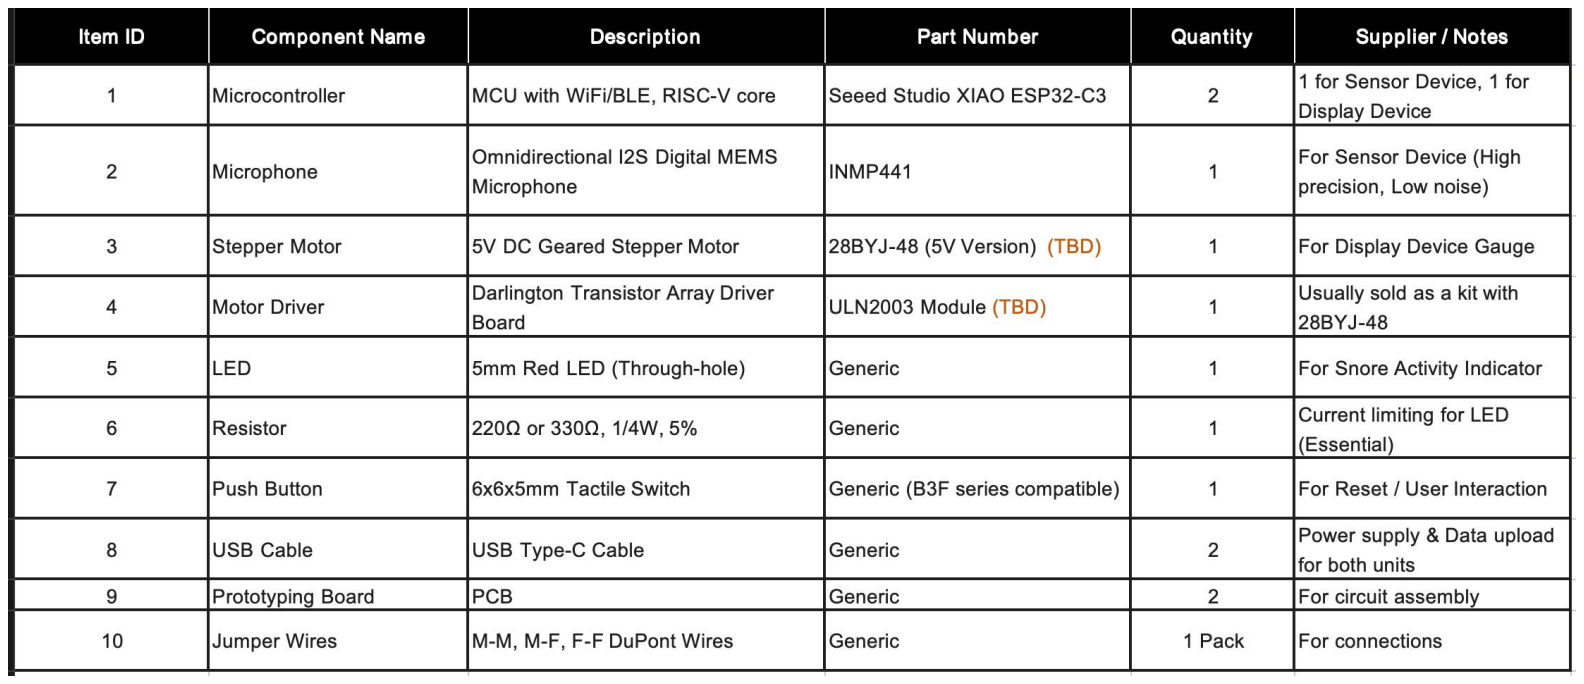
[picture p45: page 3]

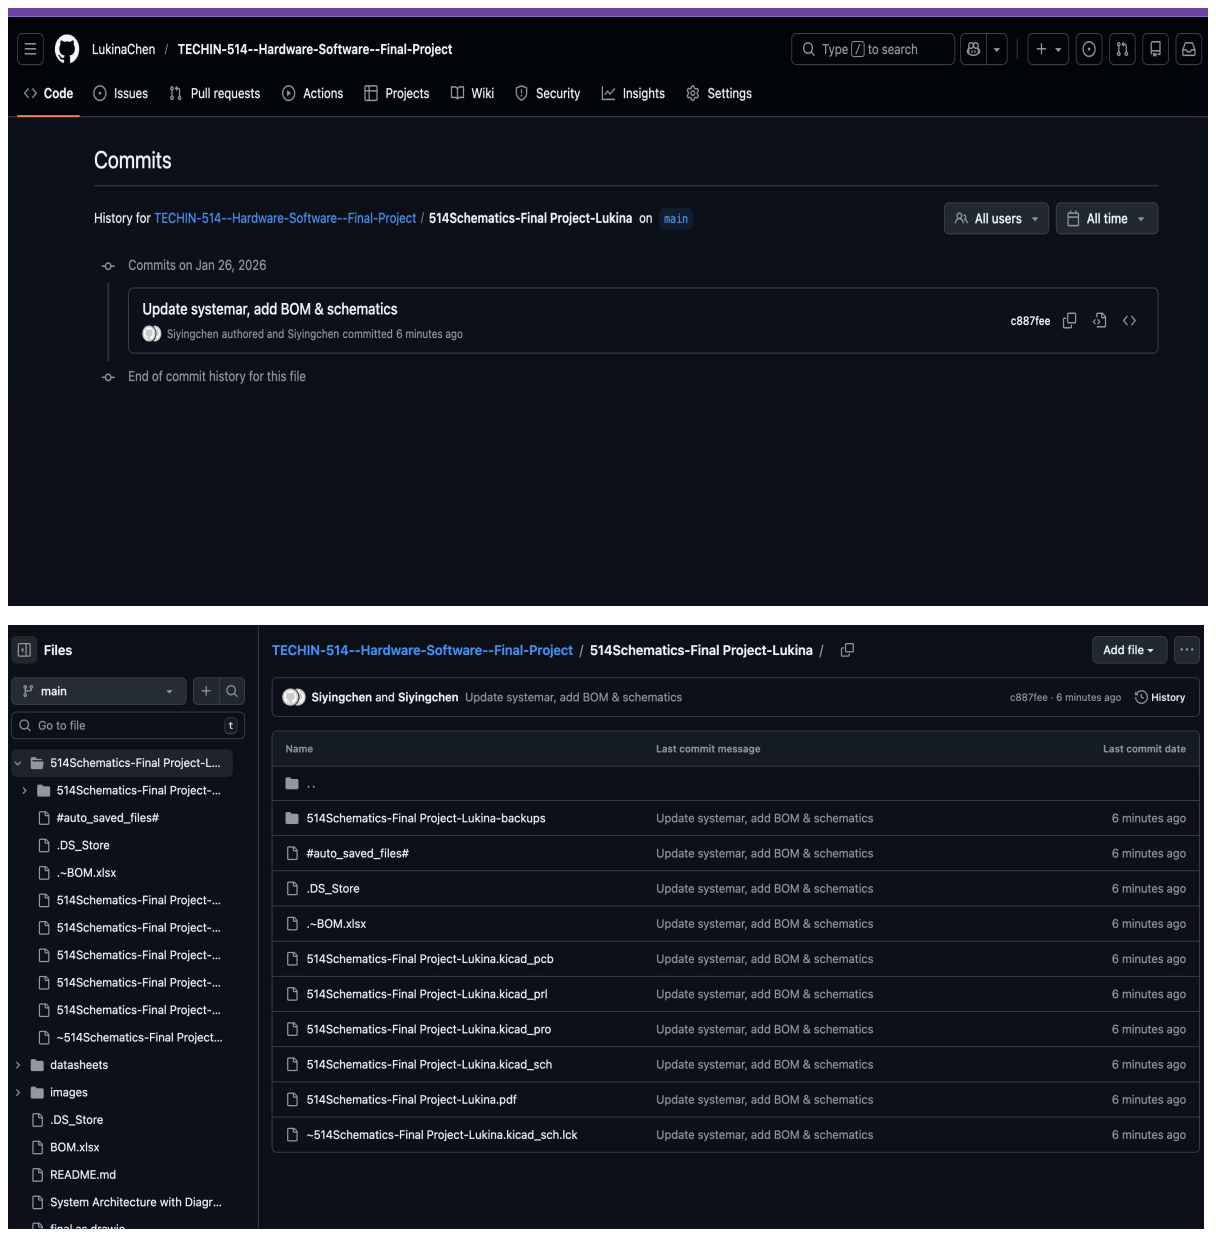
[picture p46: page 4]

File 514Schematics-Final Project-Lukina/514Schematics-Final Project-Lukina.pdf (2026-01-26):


Id: 1/1 Title: SnoreSense System Schematic

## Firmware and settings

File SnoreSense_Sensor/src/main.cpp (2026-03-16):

#include <Arduino.h>
#include <driver/i2s.h>
#include <stdint.h>
#include <WiFi.h>
#include <esp_now.h>

// --- Hardware Pins ---
#define I2S_WS 5
#define I2S_SD 4
#define I2S_SCK 3
#define LED_PIN 20  // D7/GPIO20 on Seeed XIAO ESP32C3

// --- ESP-NOW ---
uint8_t displayMAC[] = {0x58, 0x8C, 0x81, 0xAE, 0x84, 0x18};

typedef struct {
  int snoreCount;
  int boutCount;
  int score;  // 0=GOOD, 1=FAIR, 2=POOR
} SleepData;

esp_now_peer_info_t peerInfo;
int lastSentScore = -1;

void onDataSent(const uint8_t *mac, esp_now_send_status_t status) {
  Serial.printf("[ESP-NOW TX] %s\n",
    status == ESP_NOW_SEND_SUCCESS ? "SUCCESS" : "FAIL");
  
  if (status == ESP_NOW_SEND_SUCCESS) {
    for (int i = 0; i < 3; i++) {
      digitalWrite(LED_PIN, LOW);  delay(150);
      digitalWrite(LED_PIN, HIGH); delay(150);
    }
  }
}

// --- Detection Settings ---
#define SNORE_THRESHOLD 100000000LL
#define BOUT_GAP_MS 120000
#define MAX_HISTORY 50
#define SCORE_DELAY_MS 20000  // 20s before scoring

// --- Tracking Variables ---
int totalSnoreCount = 0;
int boutCount = 0;
unsigned long lastSnoreTime = 0;
int history[MAX_HISTORY];
int historyIndex = 0;
bool historyFull = false;

void setup_i2s() {
  i2s_config_t i2s_config = {
    .mode = (i2s_mode_t)(I2S_MODE_MASTER | I2S_MODE_RX),
    .sample_rate = 16000,
    .bits_per_sample = I2S_BITS_PER_SAMPLE_32BIT,
    .channel_format = I2S_CHANNEL_FMT_ONLY_LEFT,
    .communication_format = I2S_COMM_FORMAT_STAND_I2S,
    .intr_alloc_flags = ESP_INTR_FLAG_LEVEL1,
    .dma_buf_count = 4,
    .dma_buf_len = 1024
  };
  i2s_pin_config_t pin_config = {
    .bck_io_num = I2S_SCK,
    .ws_io_num = I2S_WS,
    .data_in_num = I2S_SD
  };
  i2s_driver_install(I2S_NUM_0, &i2s_config, 0, NULL);
  i2s_set_pin(I2S_NUM_0, &pin_config);
}

void setup_espnow() {
  WiFi.mode(WIFI_STA);
  WiFi.disconnect();
  if (esp_now_init() != ESP_OK) {
    Serial.println("[ERROR] ESP-NOW init failed!");
    return;
  }
  esp_now_register_send_cb(onDataSent);
  memcpy(peerInfo.peer_addr, displayMAC, 6);
  peerInfo.channel = 0;
  peerInfo.encrypt = false;
  esp_now_add_peer(&peerInfo);
  Serial.println("[ESP-NOW] Ready");
}

int calcScore(int snores, int bouts) {
  if (snores < 5 && bouts < 2) return 0;    // GOOD
  if (snores > 15 || bouts > 3) return 2;   // POOR
  return 1;                                  // FAIR
}

void sendScore(int score) {
  SleepData data;
  data.snoreCount = totalSnoreCount;
  data.boutCount = boutCount;
  data.score = score;
  
  esp_err_t result = esp_now_send(displayMAC, (uint8_t*)&data, sizeof(data));
  Serial.printf("[TX] score=%d snore=%d bout=%d esp_err=%d\n",
    score, totalSnoreCount, boutCount, result);
}

void blink_startup_test() {
  for (int i = 0; i < 3; i++) {
    digitalWrite(LED_PIN, HIGH);
    delay(250);
    digitalWrite(LED_PIN, LOW);
    delay(250);
  }
}

void setup() {
  Serial.begin(115200);
  pinMode(LED_PIN, OUTPUT);

  blink_startup_test();
  digitalWrite(LED_PIN, HIGH);

  setup_i2s();
  setup_espnow();
  Serial.println("--- SnoreSense: Power Indicator Active ---");
}

void loop() {
  int32_t maxSample = -2147483648;
  int32_t minSample = 2147483647;
  bool hasValidSample = false;

  unsigned long start = millis();
  while (millis() - start < 200) {
    int32_t sample = 0;
    size_t bytes_read;
    i2s_read(I2S_NUM_0, &sample, sizeof(sample), &bytes_read, 10);
    if (bytes_read > 0 && sample != 0) {
      hasValidSample = true;
      if (sample > maxSample) maxSample = sample;
      if (sample < minSample) minSample = sample;
    }
  }

  int64_t peakToPeak = 0;
  if (hasValidSample && maxSample > minSample) {
    peakToPeak = (int64_t)maxSample - (int64_t)minSample;
  }

  bool detected = peakToPeak > SNORE_THRESHOLD;
  bool newBout = false;
  if (detected) {
    totalSnoreCount++;
    if (lastSnoreTime == 0 || (millis() - lastSnoreTime) > BOUT_GAP_MS) {
      boutCount++;
      newBout = true;
    }
    lastSnoreTime = millis();
  }

  history[historyIndex] = newBout ? 2 : (detected ? 1 : 0);
  historyIndex = (historyIndex + 1) % MAX_HISTORY;
  if (historyIndex == 0) historyFull = true;

  int recentDetections = 0;
  int recentBouts = 0;
  int totalSamples = historyFull ? MAX_HISTORY : historyIndex;
  for (int i = 0; i < totalSamples; i++) {
    if (history[i] >= 1) recentDetections++;
    if (history[i] == 2) recentBouts++;
  }

  String finalGrade = "CALIBRATING";
  if (totalSamples >= 10) {
    if (recentDetections >= 12 || recentBouts >= 3) finalGrade = "POOR";
    else if (recentDetections >= 5 || recentBouts >= 2) finalGrade = "FAIR";
    else finalGrade = "GOOD";
  }

  // change to send each sec(Only send after 1 minute and when score changes 
  if (millis() >= SCORE_DELAY_MS) {
    int currentScore = calcScore(totalSnoreCount, boutCount);
    sendScore(currentScore);
    lastSentScore = currentScore;
  }

  digitalWrite(LED_PIN, HIGH);
  Serial.printf(
    "Peak: %lld | Detect: %s | Snores: %d | Bouts: %d | RecentDetections: %d | RecentBouts: %d | Grade: %s\n",
    peakToPeak,
    detected ? "DETECTED" : "NO",
    totalSnoreCount,
    boutCount,
    recentDetections,
    recentBouts,
    finalGrade.c_str()
  );
  delay(800);
}

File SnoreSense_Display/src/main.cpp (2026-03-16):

#include <Arduino.h>
#include <WiFi.h>
#include <esp_now.h>
#include "SwitecX25.h"
#include <driver/gpio.h>

#define LED_PIN   D8
#define BTN_PIN   D9

#define MOTOR_STEPS  1500
#define POS_START    1450
#define POS_GOOD     1286
#define POS_FAIR     958
#define POS_POOR     630

SwitecX25 motor(MOTOR_STEPS, 4, 2, 5, 3);

typedef struct {
  int snoreCount;
  int boutCount;
  int score;
} SleepData;

SleepData latestData;
bool dataReceived = false;

void onDataRecv(const uint8_t *mac, const uint8_t *data, int len) {
  memcpy(&latestData, data, sizeof(latestData));
  dataReceived = true;
  Serial.printf("[ESP-NOW RX] snore=%d bout=%d score=%d\n",
    latestData.snoreCount, latestData.boutCount, latestData.score);
}

void homing() {
  Serial.println("[HOMING] starting...");
  motor.zero();
  delay(500);
  motor.setPosition(POS_START);
  motor.updateBlocking();
  Serial.println("[HOMING] done");
}

void setup() {
  Serial.begin(115200);
  delay(500);

  gpio_reset_pin(GPIO_NUM_8);
  gpio_set_direction(GPIO_NUM_8, GPIO_MODE_OUTPUT);

  pinMode(LED_PIN, OUTPUT);
 pinMode(BTN_PIN, INPUT_PULLUP);

  for (int i = 0; i < 5; i++) {
    digitalWrite(LED_PIN, HIGH); delay(200);
    digitalWrite(LED_PIN, LOW);  delay(200);
  }
  digitalWrite(LED_PIN, HIGH);

  Serial.println("=== SnoreSense Display BOOT ===");

  homing();

  WiFi.mode(WIFI_STA);
  WiFi.channel(1);
  if (esp_now_init() != ESP_OK) {
    Serial.println("[ERROR] ESP-NOW init failed!");
  } else {
    esp_now_register_recv_cb(onDataRecv);
    Serial.println("[ESP-NOW] ready - waiting for sensor...");
    Serial.print("[INFO] Display MAC: ");
    Serial.println(WiFi.macAddress());
  }
}

unsigned long btnPressStart = 0;
bool btnWasPressed = false;
#define LONG_PRESS_MS 2000

void loop() {
  if (dataReceived) {
    dataReceived = false;
    int target = POS_GOOD;
    if (latestData.score == 1) target = POS_FAIR;
    if (latestData.score == 2) target = POS_POOR;
    motor.setPosition(target);
    motor.updateBlocking();
  }

  bool btnPressed = (digitalRead(BTN_PIN) == LOW);
  if (btnPressed && !btnWasPressed) {
    btnPressStart = millis();
    btnWasPressed = true;
  }
  if (!btnPressed && btnWasPressed) {
    if (millis() - btnPressStart >= LONG_PRESS_MS) {
      homing();
      digitalWrite(LED_PIN, HIGH);
    }
    btnWasPressed = false;
  }

  delay(20);
}

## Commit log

2026-01-19 Add system architecture and device descriptions for SnoreSense
2026-01-19 Update README with display device sketch
    Added display device sketch image to README.
2026-01-19 Revise hardware component details in README
    Updated key hardware components for sensing and display devices.
2026-01-26 Update systemar, add BOM & schematics
    [514Schematics-Final Project-Lukina.kicad_pcb, 514Schematics-Final Project-Lukina.kicad_sch, BOM.xlsx]
2026-02-06 Refine the display part with new switch and motor.
    Also refined the sensor part description.
2026-02-06 datasheet update & file cleaning & display device pcb design
    [BOM.xlsx, SnoreSense_Display_PCB_v1.kicad_pcb, SnoreSense_Display_PCB_v1.kicad_sch]
2026-02-07 Battery estimate HW & update led datasheet
    [Battery Life Estimate.xlsx]
2026-02-07 Battery management update
    [Battery Estimate.xlsx, Battery Life Estimate.xlsx]
2026-02-22 Add displa pcb-v3+display enclosure
    [Bottom_Case-Lukina.stl, Display_Enclosure_Native.f3d, Enclosure-Display_step.step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]
2026-02-24 newline retry
    Removed duplicate entries for stepper motor and indication components in the display device section.
2026-02-28 Sensor Device- V1
    [Buttom case- Lukina.stl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]
2026-03-01 add sensor code
2026-03-16 Display code update( now with shorter time for display)
    [Bottomcase--Lukina.stl, Bottomcase-Lukina.stl, Needle1-Lukina.stl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]
